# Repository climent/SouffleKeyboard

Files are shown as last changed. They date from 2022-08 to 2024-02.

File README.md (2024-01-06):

# Soufflé Keyboard

The Soufflé Keyboard is 6×4+1+4+1 keys column-staggered split keyboard with encoder support, based on the [Sofle](https://github.com/josefadamcik/SofleKeyboard) and re-inspired by the [Lily58](https://github.com/kata0510/Lily58) keyboards. It also takes a bit of layout ideas from the Kyria and the Ferris Sweep.

Soufflé was created by [Jesus Climent](https://https://github.com/climent/).

Key features:

*   Originally based on the Sofle V1 release layout,
    *   the two pinky columns have been lowered in the Soufflé: ~5mm for the V2, ~10mm for the V3 Sweep
    *   the thumb cluster has been repositioned to allow for equal reach of the keys
    *   a palm key has been added at the bottom of the outer pinkie column
*   Choice between rotary encoder or key switch for the inner keys.
*   Redone track layout with simplified, curved tracks.
*   V3 adds support for nice!nano with solder points for a battery and a power switch. 
*   Removed i2c communication betweek halves.

The VR release is a result of me experimenting with the RGB layout. However, I could not adapt to the displaced thumb cluster, so I returned to the V1 layout when I designed the V2.

## Images of keyboard

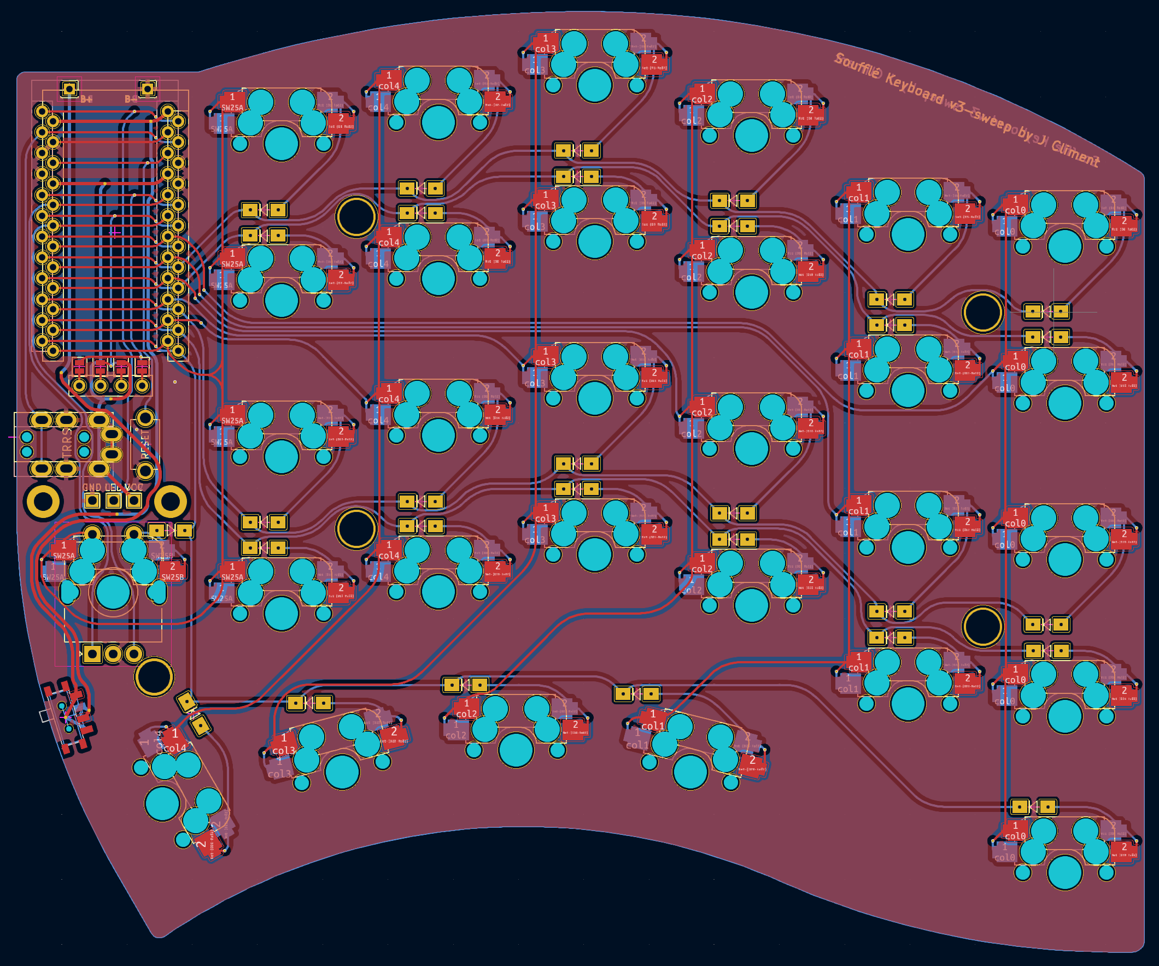
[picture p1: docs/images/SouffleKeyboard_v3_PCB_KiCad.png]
SouffleKeyboard PCB

SouffleKeyboard V3

## Build notes

Build guide will be added soon. Meanwhile, the [Sofle Build Guide](https://josefadamcik.github.io/SofleKeyboard/build_guide.html) should be a good starting point.

## BOM

| Item | Quantity | Notes |
|---|---|---|
| Soufflé PCB | 2 | |
| Soufflé Plates | 2+2 | Gerber files are provided to be ordered made of FR4. Can be 3D printed, extruding the upper plate at 1.5mm, the lower at a minimum of 1.5mm. |
| Pro Micro pin MCU, or equivalent. | 2 | RP2040 recomended. Alternatives: Pro Micro (or clone), Elite-C, Elite-Pi, Frood, Liatris, nice!nano (for BT wireless) |
| 1N4148W Diodes | 60 | |
| Kailh MX hotswap switch sockets | 60 | |
| MX switches | 60 | |
| 1u keycaps | 60 | |
| M2, 7 mm brass (or other material) spacers | 10 | These are the optimal spacers. Longer ones work, too, but with 7mm the gap is minimal. |
| M2x0.4mm, 5mm length flat head screws | 20 | |
| M2x0.4mm, 7mm length flat head screws | 4 | If using OLED screen plexiglass protectors. |
| PJ-320A TRRS 3.5mm Audio Jack Connector Through Holes | 2 | Not necessary if you are using wireless, via nice!nano. |
| Surface Momentary Tact Switch, 3mm x 4mm x 4.3mm | 2 | |
| 2.54mm Round Hole Male Tin Gold Female Pin Headers, 40p | 2 (opt)  | HIGHLY RECOMMENDED. However, If you want to solder the MCU directly to the board, these are not necessary. |
| Mill Max socket pins | 48 (opt) | Add 8 extra for the OLED screen, if used. Alternatively, socketing can also be done with diode legs. |
| 1.25u keycaps | 2 (opt)  | Alternative to 2x 1u keycaps. |
| SSD1306 128x64 OLED | 2 (opt)  | |
| EC11 Encoder | 2 (opt)  | Optional, as the board allows for either 2x encoders or switches. |
| Encoder knob, 16mm | 2 (opt)  | If encoders are used. |
| M2, 10 mm brass (or other material) spacers | 4 (opt)  | If using OLED screen plexiglass protectors. |
| MSK12C02 power switches | 2 | If using nice!nano MCUs and batteries, for BT wireless. |
| Battery, 10mAH | 2 | If using nice!nano MCUs and batteries, for BT wireless. |
| TRRS audio cable, for connecting both sides | 1 (opt)  | Not necessary if you are using BT wireless, via nice!nano. |

## Firmware 

Soufflé uses [QMK firmware](https://qmk.fm/) and it is fully compatible with the Sofle firmware.

## Default layout 

Soufflé uses a similar layout than the Sofle, with a full 6x5 matrix, and the encoders connected to the same pins. The main difference is the position of the outermost thumb key, which has been moved to the bottom of the pinky column, to be used with the palm.

## Older versions

In this repository you will find several  releases of the Soufflé Keyboard:

*   V1: Based on the Sofle v1 and the Lily58. Key features:
    *   Added the palm key at the bottom of the pinky column.
    *   Some re-routing done and some label fixes, but modtly unchanged from the Sofle v1.
*   VR: Based on the Sofle RGB. Key features:
    *   Same palm key configuration as the V1.
    *   The layout footprint is based on the RGB, and thus the thumb cluster is slightly displaced to the center (compared to the V1).
    *   The encoder footprint shares a switch footprint, allowing for the user to choose what to put there.
    *   Pins for the encoder/switch have been exposed, as the top case plate can accommodate a roller encoder.
*   V2: Based on the Soufflé V1. Key features:
    *   Same palm key configuration as the V1.
    *   Pinkie columns have been lowered.
    *   Thumb cluster repositioned, to make the keys slightly more accessible.
    *   The encoder footprint shares a switch footprint, allowing to choose what to put there.
    *   Removed I2C connectivity option.
    *   Curved contour of the keyboard.
*   V3: Based on the Soufflé V2, and the Ferris Sweep layout. Key features:
    *   Wireless compatible with Nice!Nano MCUs.
    *   Same palm key configuration as the previous releases.
    *   Pinkie columns have been lowered even further, similar to the Ferris Sweep keyboard.
    *   Middle finger column has been raised, similar to the Ferris Sweep keyboard.
    *   Thumb cluster repositioned, to make the keys slightly more accessible, as the V2.
    *   The encoder footprint shares a switch footprint, allowing to choose what to put there, as the V2.
    *   The reset button has been repositioned, and is accessible through a hole in the lower plate.
    *   Added battery connection points, and a power switch, for use with nice!nano.
    *   Removed I2C connectivity option.
    *   Curved contour of the keyboard.
*   V3.1: Small upgrade to the V3
    *   Added a compatibility pin for Nice!View screens.

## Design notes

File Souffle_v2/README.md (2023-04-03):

# Soufflé Keyboard v2

Soufflé v2 is 6×4+1+4+1 keys column-staggered split keyboard with encoder, OLED, and palm key support. It is an evolution of the Soufflé V1 and VR keyboard, with a slightly more aggressive arrangement of the pinkie columns.

Soufflé V2 was created by [Jesus Climent](https://https://github.com/climent/).

Key changes compared to the Soufflé V1:

*   Pinkie columns have been lowered ~5mm, to make them more accessible.
*   Thumb cluster repositioned, to make the keys slightly more accessible.
*   It is now possible to use switches in the position of the 2x rotary encoders.
*   Curved contour of the plates.

## Firmware 

Soufflé v2 uses [QMK firmware](https://qmk.fm/) and it is fully compatible with the Sofle firmware.

## Images of keyboard

SouffleKeyboard V2 top view
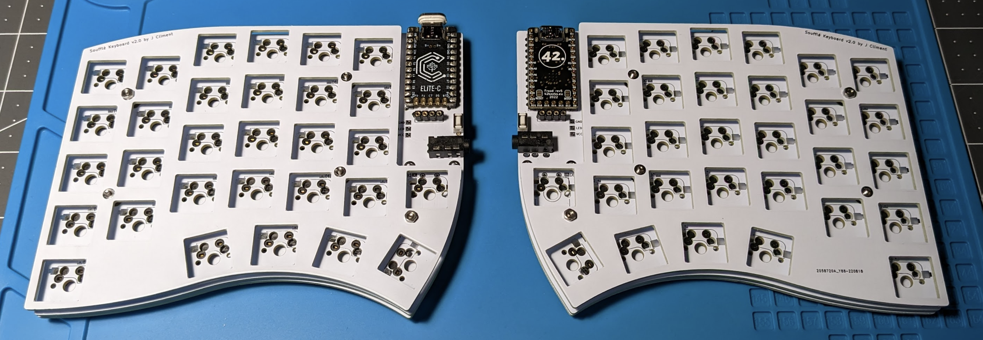
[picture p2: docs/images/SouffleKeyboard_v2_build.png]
SouffleKeyboard V2 build picture


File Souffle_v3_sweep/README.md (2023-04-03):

# Soufflé Keyboard v3 Sweep

Soufflé v3 is 6×4+1+4+1 keys column-staggered split keyboard with encoder, OLED, palm key and nice!nano support. It is an evolution of the Soufflé V2 keyboard, with a more aggressive arrangement of the pinkie columns.

Soufflé V3 Sweep was created by [Jesus Climent](https://https://github.com/climent/).

Key changes compared to the Soufflé V2:

*   Pinkie columns have been lowered ~5mm (~10mm compared to V1), to make them more accessible.
*   Middle finger column has been raised ~3mm.
*   Reset button has been moved to an internal position, and the lower plate has a hole, making it accessible from the bottom of the keyboard.
## Firmware 

Soufflé v3 Sweep uses [QMK firmware](https://qmk.fm/) and it is fully compatible with the Sofle firmware.

## Images of keyboard

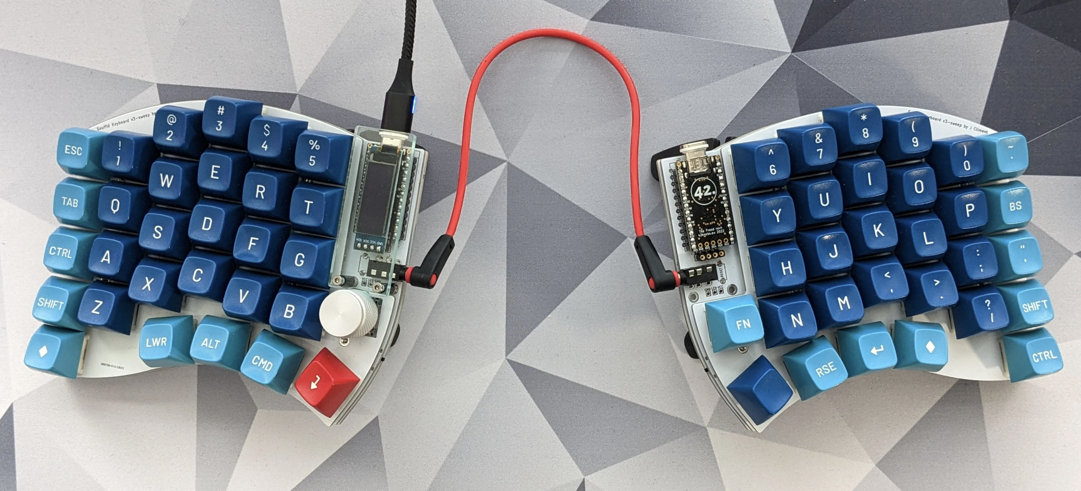
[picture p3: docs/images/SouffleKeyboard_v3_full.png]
SouffleKeyboard PCB

SouffleKeyboard PCB
SouffleKeyboard PCB

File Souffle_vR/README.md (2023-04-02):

# Soufflé Keyboard

Soufflé vR is 6×4+1+4+1 keys column-staggered split keyboard with encoder support, based on the [Sofle](https://github.com/josefadamcik/SofleKeyboard) RGB version, and re-inspired by the [Lily58](https://github.com/kata0510/Lily58) keyboard.

Soufflé was created by [Jesus Climent](https://https://github.com/climent/).

Key features:

*   Palm key at the bottom of the outer pinky column.
*   2x rotary encoders.
*   Original RGB features were removed.
*   Exposed pins for roller encoder on the upper case plate. 
*   More (to be listed).

## Firmware 

Soufflé uses [QMK firmware](https://qmk.fm/) and it is fully compatible with the Sofle firmware.

## Default layout 

Soufflé uses a similar layout than the Sofle, with a full 6x5 matrix, and the encoders connected to the same pins. The main difference is the position of the outermost thumb key, which has been moved to the bottom of the pinky column, to be used with the palm.

## Images of keyboard

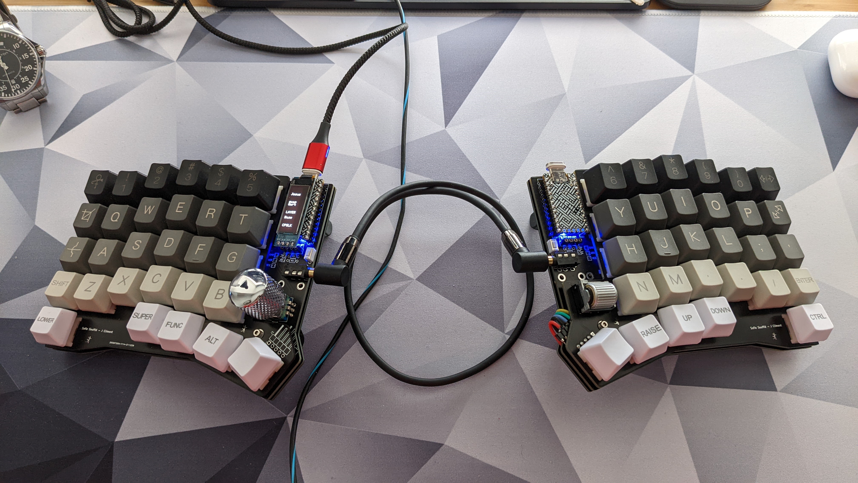
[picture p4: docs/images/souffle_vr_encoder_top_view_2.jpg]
SouffleKeyboard PCB


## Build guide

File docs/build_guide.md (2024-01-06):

---
layout: default
title: Soufflé Keyboard - build guide (v3)
---

This guide is for the V3 (Sweep release) of the Soufflé keyboard, but it can serve as a base guide for any other Soufflé revision.

If you don't have all the necessary parts, please read about [how to source the parts][sourcing].

## Bill of materials

The following is needed to build the keyboard. You can find [links for the most of the components in the sourcing parts section][sourcing].

- **2 PCBs** (see [sourcing][sourcing])
- **2 top plates**, **2 bottom plates** for a sandvich-case build. (see [sourcing][sourcing])
- **58-60 keyboard switch sockets by Kailh**. The PCB supports only MX switches. A Choc version of the Soufflé keyboard will be available some time in the future. They are available on Aliexpress, Splitkb.com and others. 
- **58-60 keyboard MX switches** of your preference.
- **58-60 keycaps**. You can use either all in `1u` size but it looks nicer with two `1.5u` for the thumb keys.
- **58-60 diodes  1N4148W**. They are surface mount diodes in SOD123 package.
- **2 TRRS connectors**. The same type which is used for Corne, Lily58 etc.
- **2 tactile buttons** through-hole, 2 pins. Technically optional: you can use metal tweezers whenever you need to reset the microcontroller.
- **1 TRRS cable**. TRS should work.
- **10 7mm M2 spacers**. They will hold the bottom and the top together. 
- **4 10mm M2 spacers**. Needed to hold transparent OLED cover but even though there are mounting holes in the PCB.
- **20 (+8) 5mm M2 screws**. 20 are going to hold the boards together (via spacers).
- **10 adhesive rubber feet**. They are really important, trust me.
- **0-2 ssd1306 128x32 OLED display module**. Very common everywhere. 
- **2 OLED covers** Optional. OLED cover should be cut from transparent acrylic. Source file for [version 1 is avalalble in the Sofle repostiory](https://github.com/josefadamcik/SofleKeyboard/tree/master/Sofle_v1/Case).
- **0-2 Rotary encoders EC11**, optional. The Soufflé is ready to accept either switches or encoders in one position.
- **A matching knob** for each encoder. 
- **2 Pro Micro** board or clone. With 2x12 pins. Just make sure you **don't** buy something like Arduino Micro (a different pinout) or Arduino Mini (different microcontroller). You could also use Elite-C which in basically a Pro Micro with USB-C. New microcontrollers based on the Raspberry Pico (rp2040) are available, and have more memory.
- **4x12 pin header (and optionally socket)** for Pro Micros. There are several ways how to mount Pro Micros to the board. Either the male PIN headers you most likely got with the board from the supplier could be used to solder it directly to the board. Build guides for Helix, Corne and Lily58 suggest [those spring pin headers][springpinheader] which are very compact and give you non-permanent connection (you can remove or replace Pro Micros). Another possible approach [is described at splitkb.com][promicrosocketing].
- **2x4 pin header (and optionally socket)** for OLEDs. I have used the most common 1x4 female pin sockets which are quite tall but they also fit the height of ProMicro with the sockets I have used. Unfortunately, the pin headers on my OLED modules (again those very common square male headers you would get with the modules) are loose in the sockets. It works but it's fiddly. I'll have to find a better solution.
- **USB Cable** to connect the keyboard to a computer. As a favourite, I use magnetic cables, to avoid putting too much stress into the USB connector.

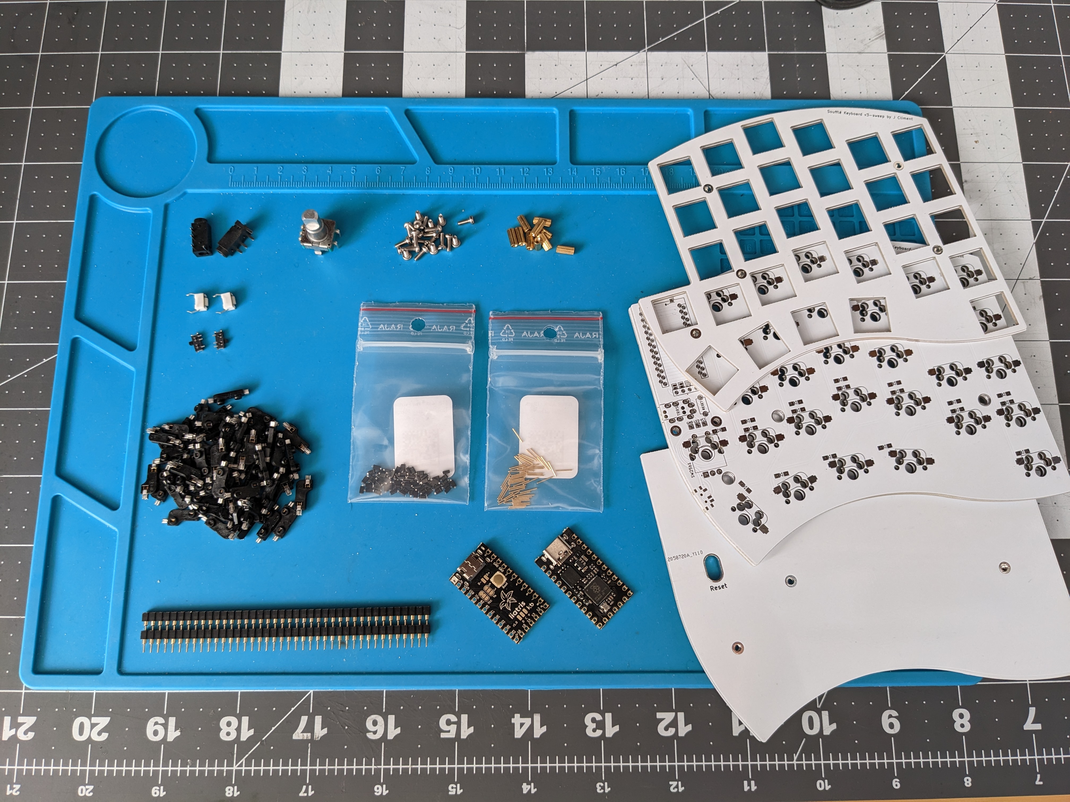
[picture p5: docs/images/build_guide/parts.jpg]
SouffléKeyboard parts


That's it. There are no RGB LEDs on the board. But if you really need underglow it is be possible to connect an RGB LED strip since there are 3 pads (VCC, GND and data) on the board. You would need to add support to the firmware on your own.

## Tools and materials

- soldering iron
- solder wire
- good tweezers, preferably non-magnetic
- masking tape
- isopropyl-alcohol for cleaning 
- screwdriver

## Warnings and disclaimers

- Think twice, solder once. Desoldering is frustrating and it's easy to mess up things.
- Don't connect or disconnect the TRRS cable when the keyboard is powered. It may short out. Always disconnect the USB cable first.
- If you are not using magnetic cables, be gentle with the USB on your microcontroller. They are easy to break.

## Steps

### Prepare

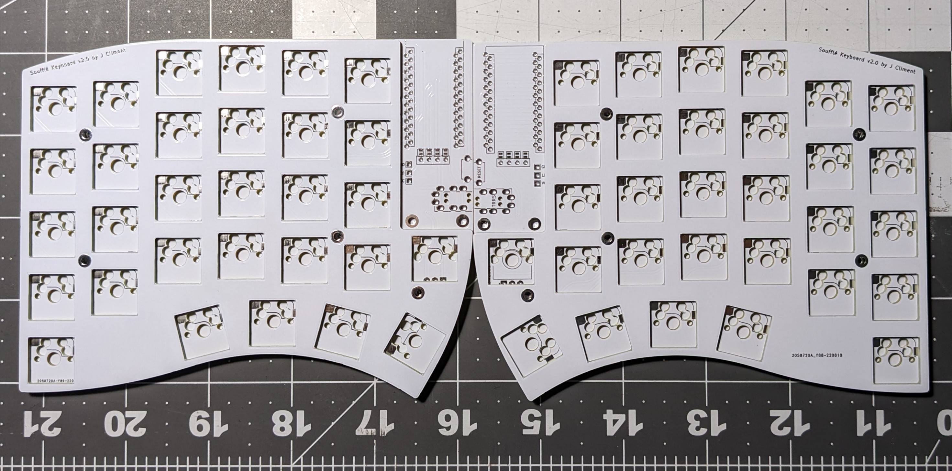
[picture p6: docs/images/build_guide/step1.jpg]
Step 1


Make sure you have all the right parts for the keyboard, specially the PCB and the top and bottom plates match. Some people mark the top/bottom of the keyboard with masking tape. I owrk with both PCBs at the same time, thus making sure I am soldering the right side on both PCBs.

### Components on the backside 

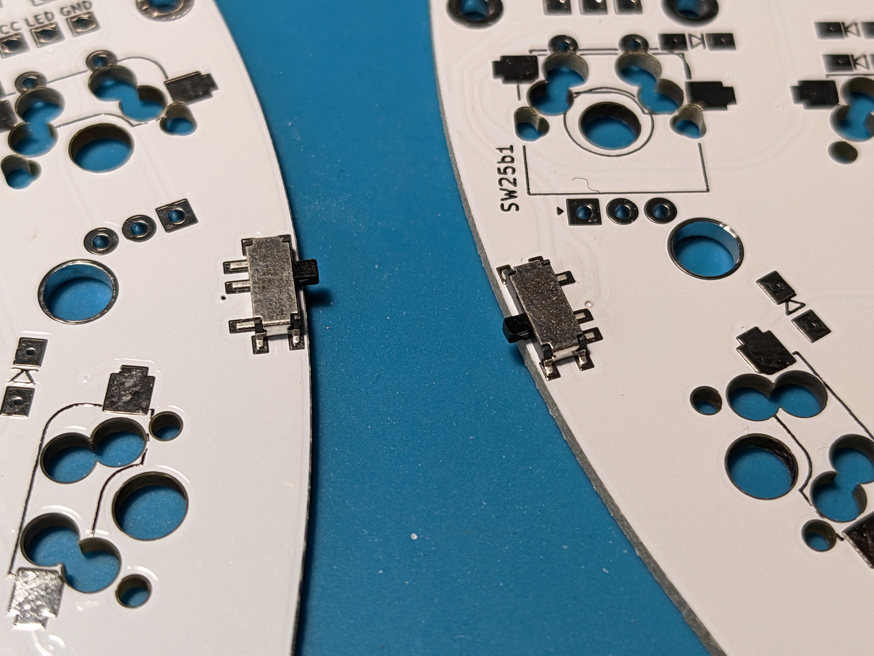
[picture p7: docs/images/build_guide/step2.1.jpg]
Step 2.1

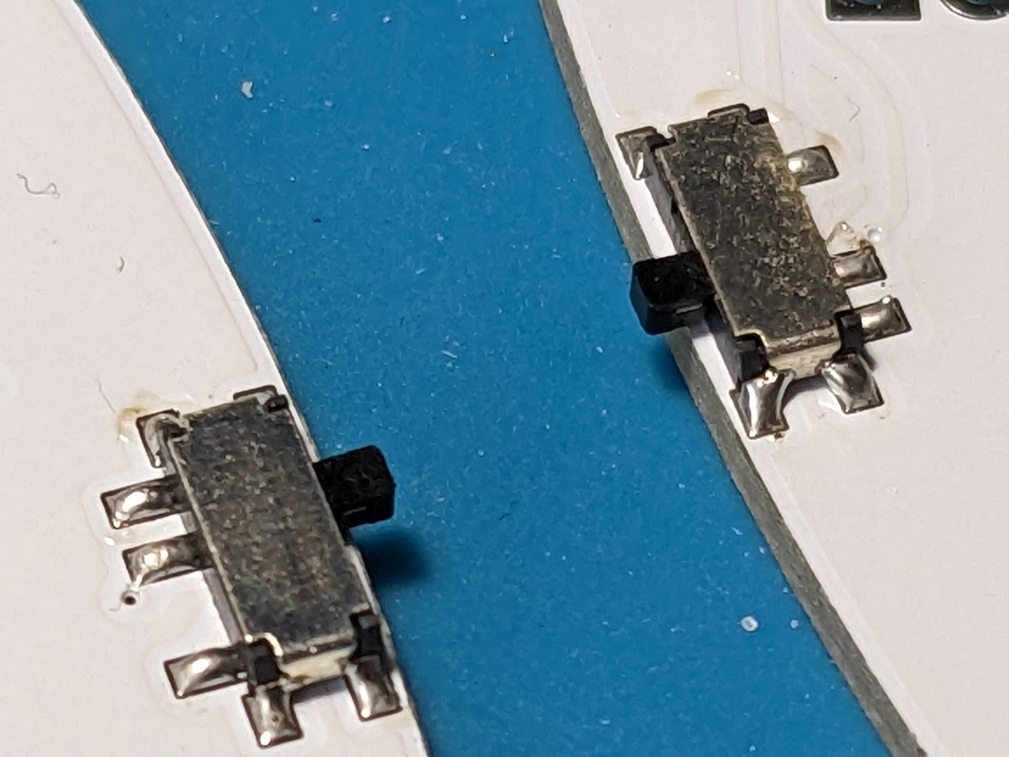
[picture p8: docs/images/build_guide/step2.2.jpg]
Step 2.2


Only if you are using, or plan to use, nice!nano microcontrollers.

Start with the power switches. Place them on the bottom side of the boards, and solder the pins to the PCB.

Next step is the diodes. They go on the backside of the PCB. Make sure you have orientation right. The end with the thin line is Cathode (-) and it should go in the direction of the "arrow" symbol on the PCB.

Step 3.1
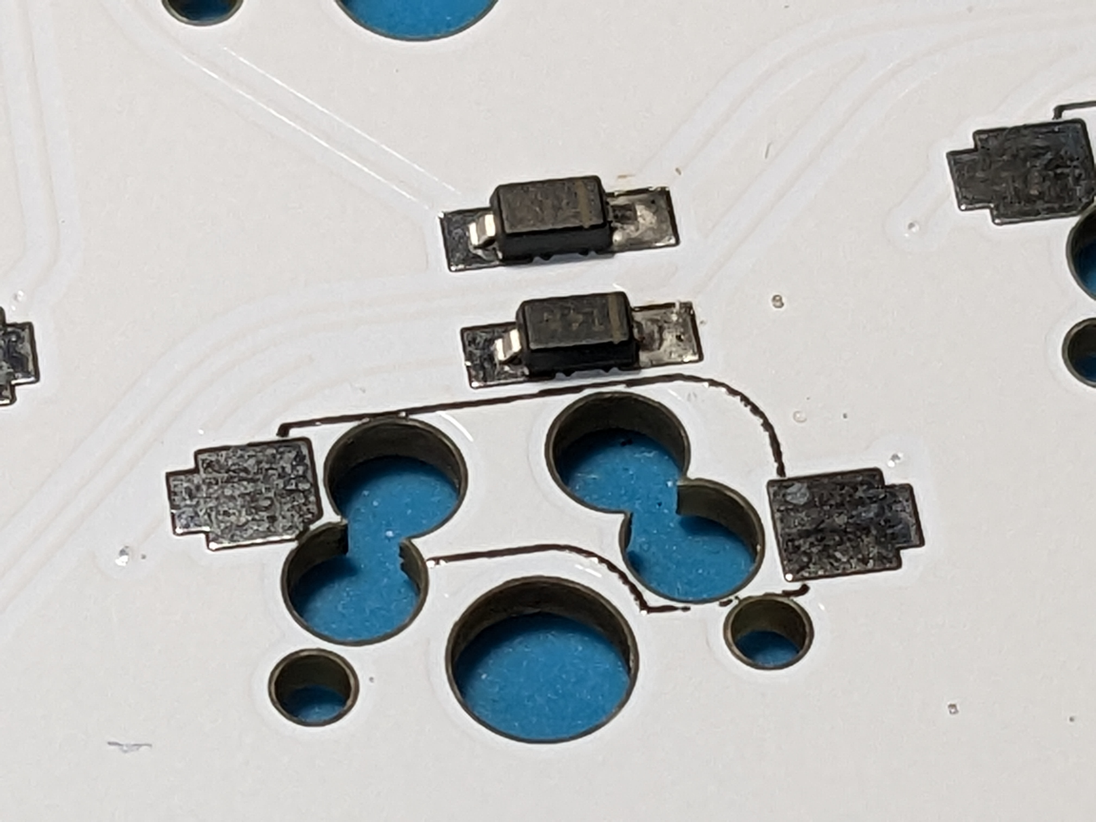
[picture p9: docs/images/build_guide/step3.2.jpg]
Step 3.2


Add a bit of solder wire to one of the two diode pads on every diode footprint of both boards. This way you can then solder one of the diode's side without needing 3 hands: one for the solder iron, one for the diode, and one for the solder wire. Use the antimagnetic tweezers to hold the diode while re-heating the solder paste on the pad, and making sure you place the diode with the correct orientation.

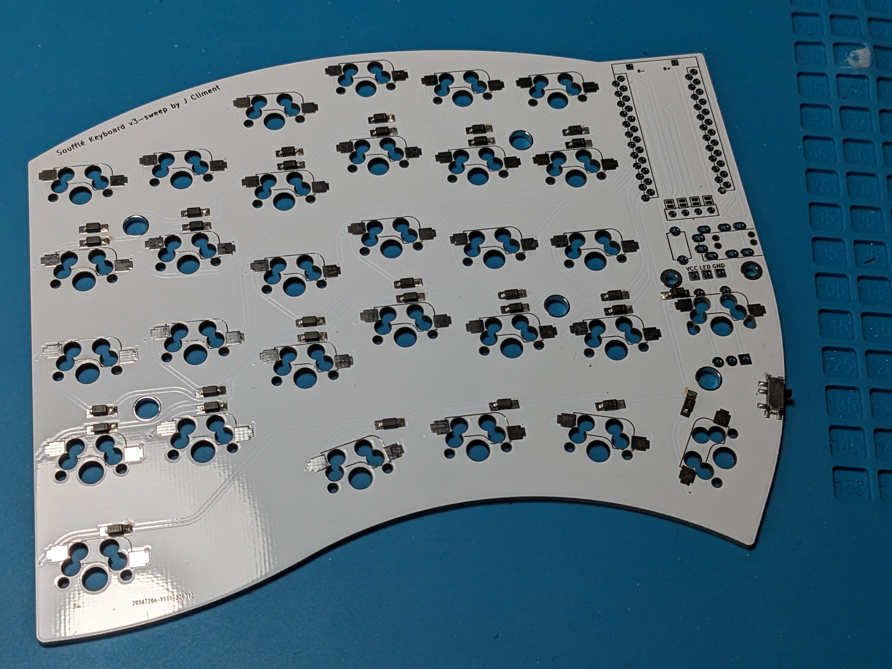
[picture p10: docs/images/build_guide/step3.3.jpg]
Step 3.3

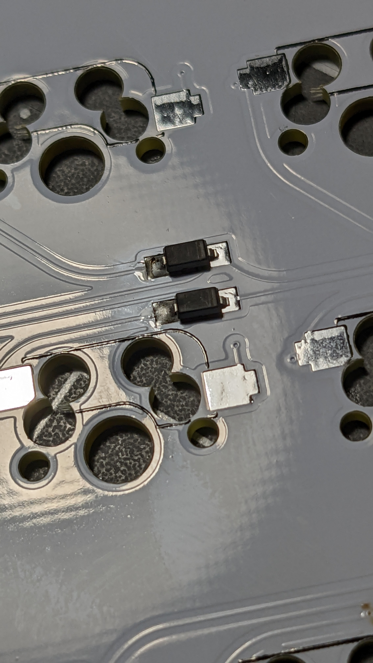
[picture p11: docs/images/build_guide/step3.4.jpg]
Step 3.5

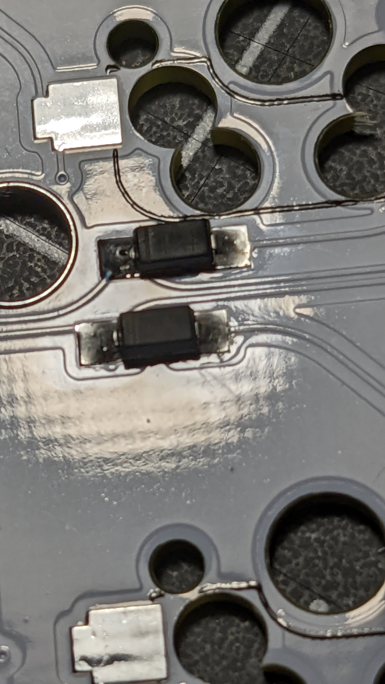
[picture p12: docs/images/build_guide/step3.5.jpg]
Step 3.4


Finally, solder the other pad and complete the diodes on both sides.

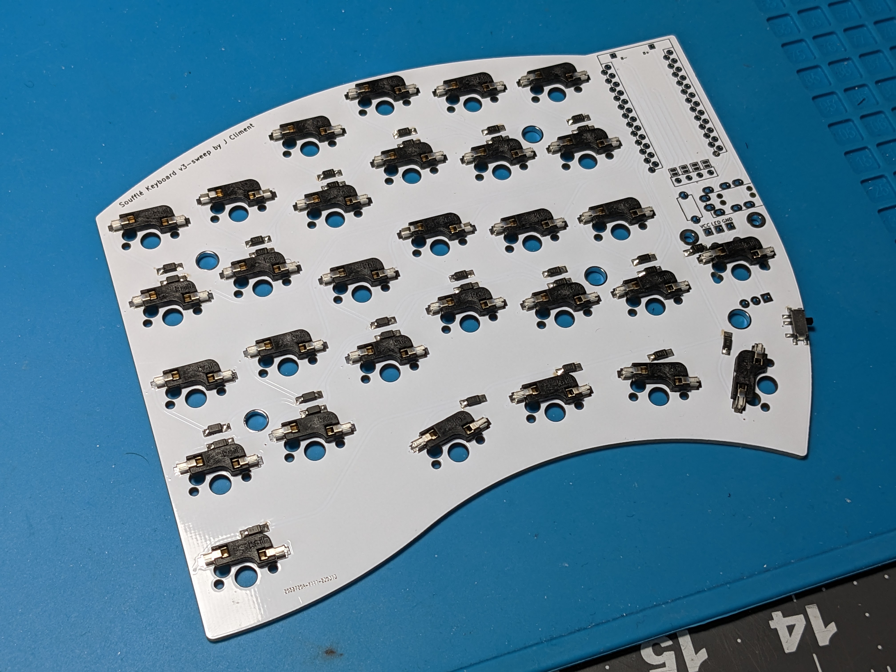
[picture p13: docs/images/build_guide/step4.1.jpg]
Step 4.1


The sockets for the switches belong again on the back side, the same side as diodes. Make sure they are flush with PCB. Watch the markings on the silkscreen which show the correct orientation.

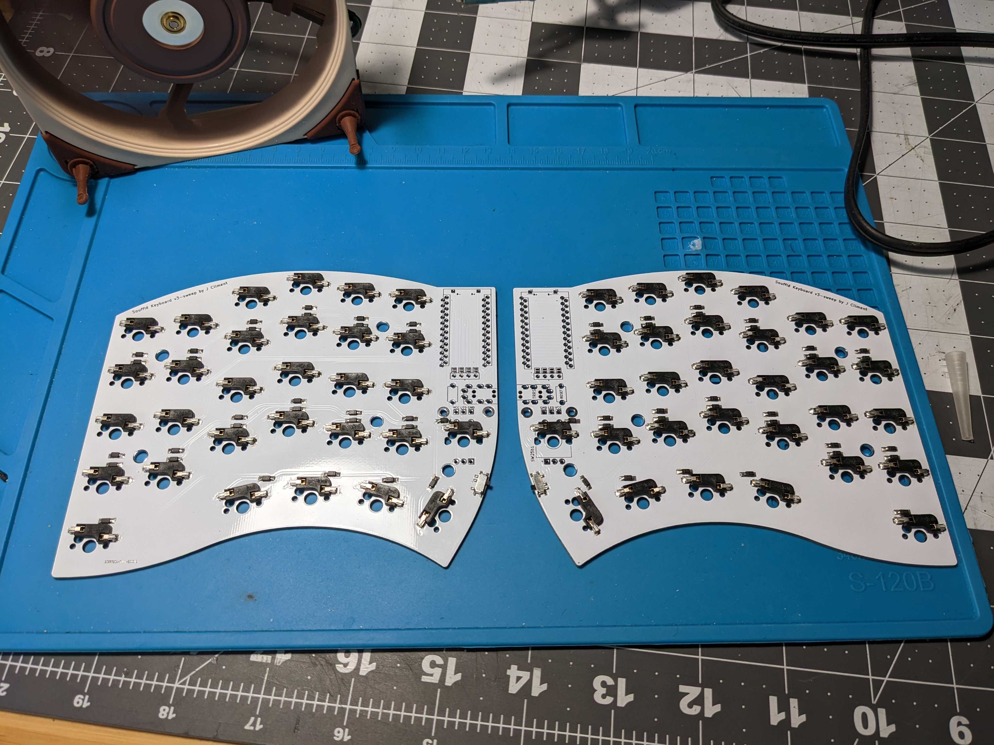
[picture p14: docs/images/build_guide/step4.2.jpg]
Step 4.2


Soldering one pad of the socket for all the sockets at once, approaching the sockets from the same side, makes it easier to work with them. Once one side is soldered, turn around the PCB and solder the other pad.

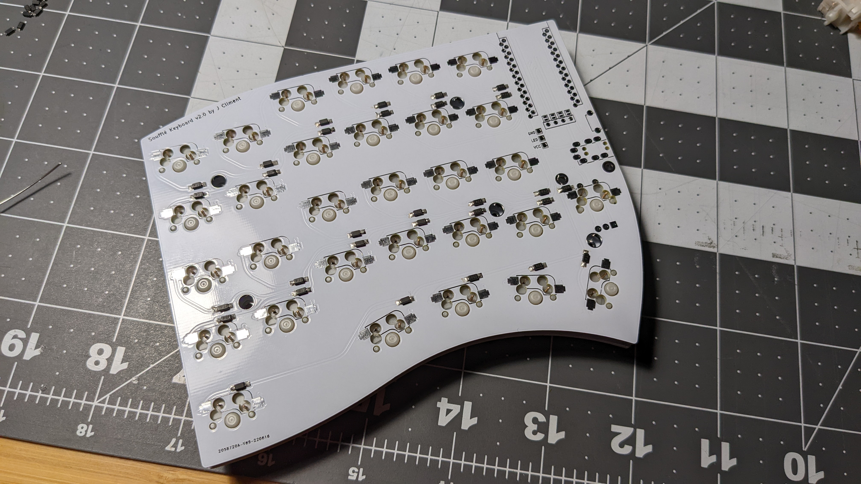
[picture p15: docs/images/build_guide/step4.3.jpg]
Step 4.3


A way to keep the MX sockets in place while soldering them is by using the switches. Put the switches in place (upper side of the PCB), and add the sockets to the bottom side. Now soldering sould be easier.

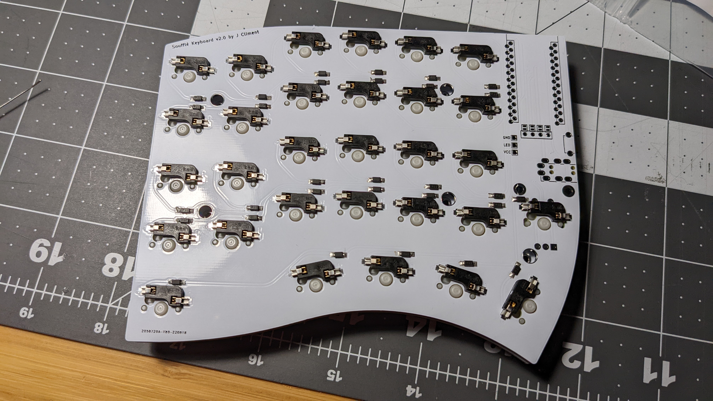
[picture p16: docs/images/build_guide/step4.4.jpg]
Step 4.4

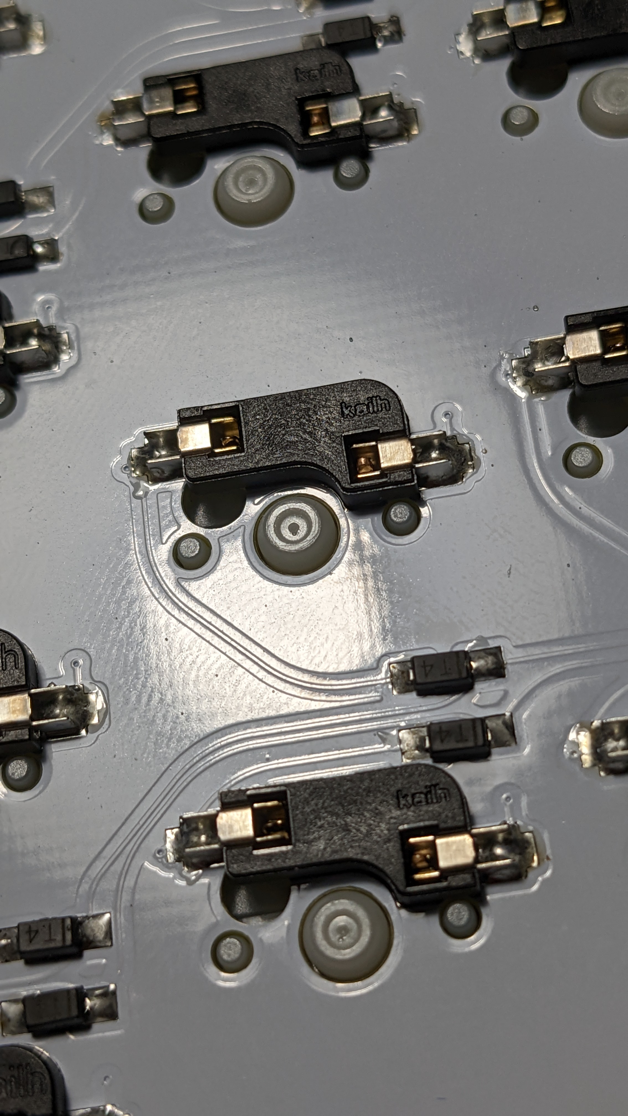
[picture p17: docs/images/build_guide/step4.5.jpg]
Step 4.5


### Components on the front side

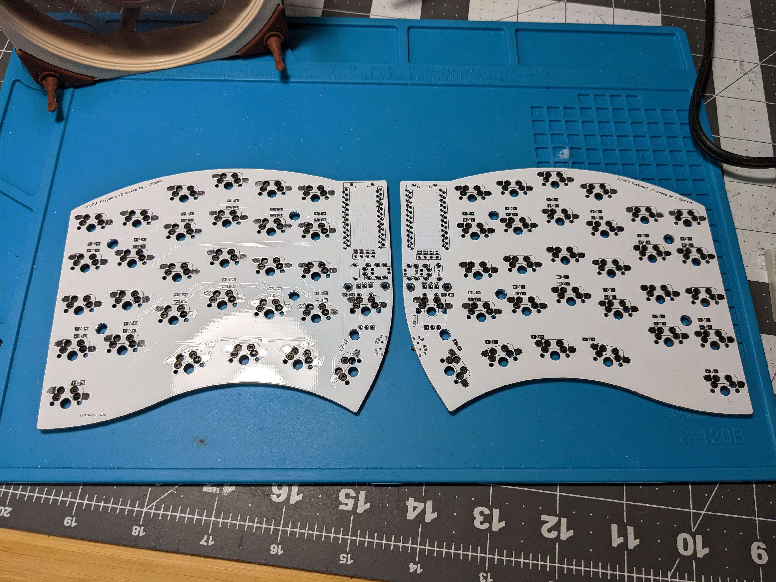
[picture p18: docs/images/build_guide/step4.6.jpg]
Turn the PCBs around


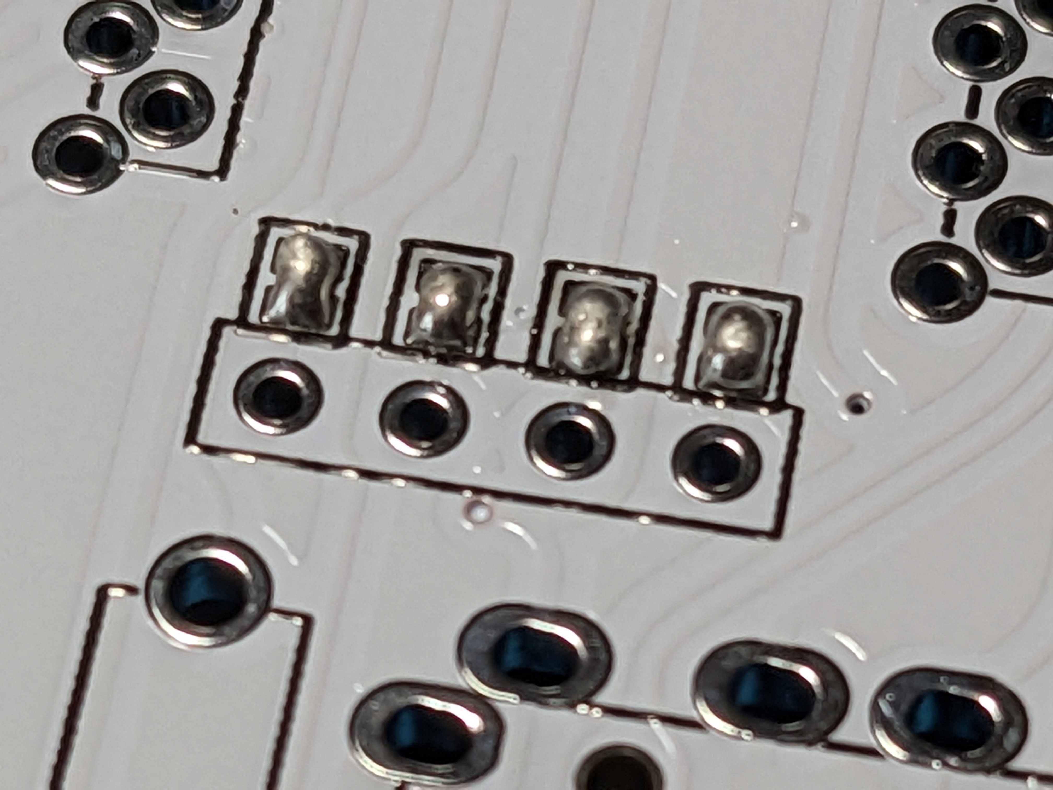
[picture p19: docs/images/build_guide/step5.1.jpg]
Step 5.1

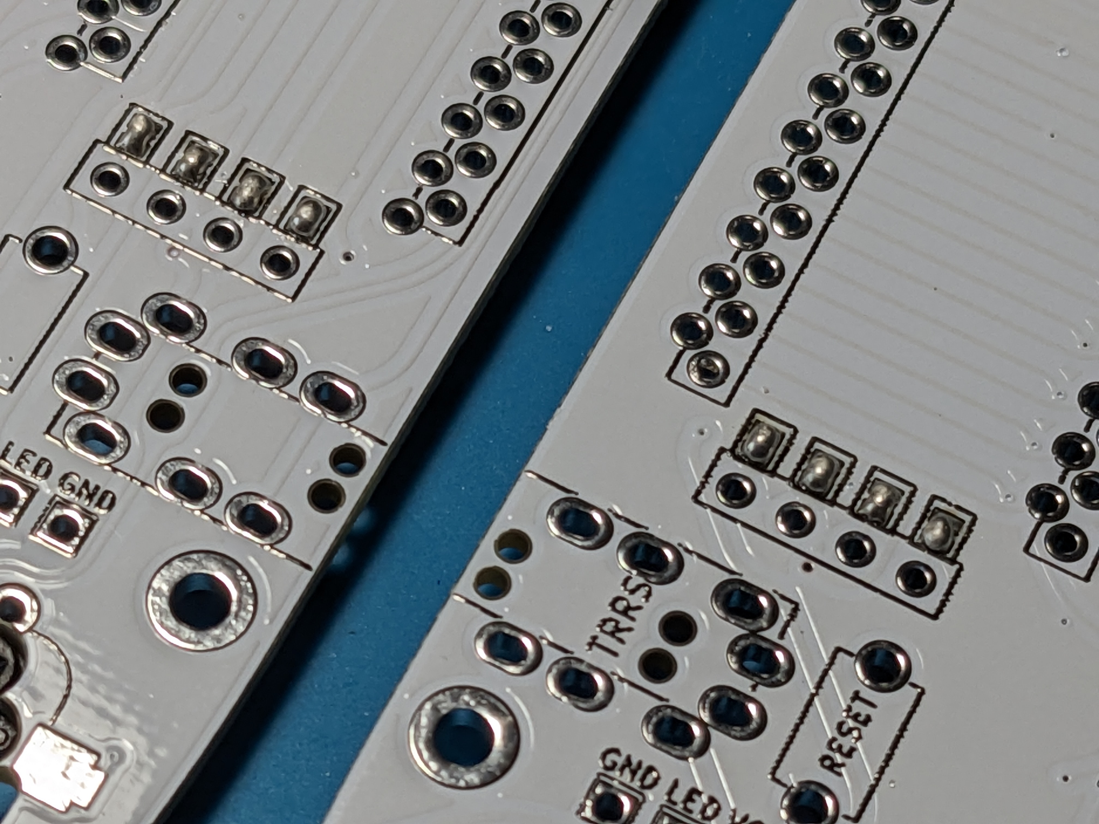
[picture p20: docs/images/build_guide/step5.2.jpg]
Step 5.2


Solder the jumper pads for the OLED on the top side of the PCB.

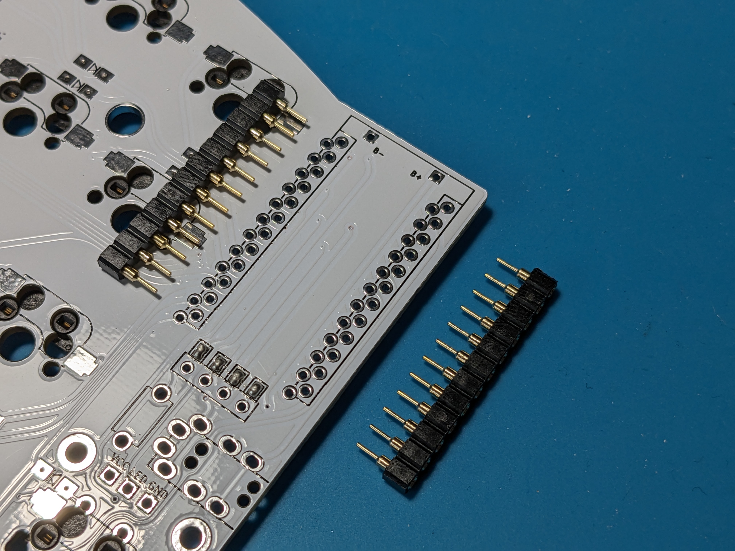
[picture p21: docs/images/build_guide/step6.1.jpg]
Step 6.1

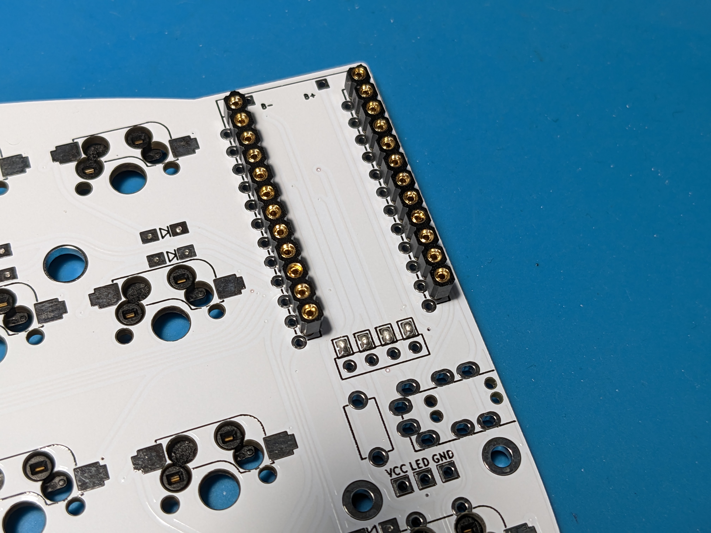
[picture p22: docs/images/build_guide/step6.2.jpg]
Step 6.2


If you are using sockets for the microcontrollers, place them on each side covering the marked rectangle. This way the microcontroller will go face down.

Although sockets are optional, I encourage you to use them. If you solder the microcontrollers directly to the PCB and there are problems with them, you will have a hard time desoldering them.

Note: if for whatever reason you want to place the microcontrollers with the chip facing up (some boards come with LEDs, or boot/reset switches on the upper side, or you are planning to place a small battery under the microcontroller, and want to avoid the chip and the components using that space), you can place the sockets on the non-marked pin holes.

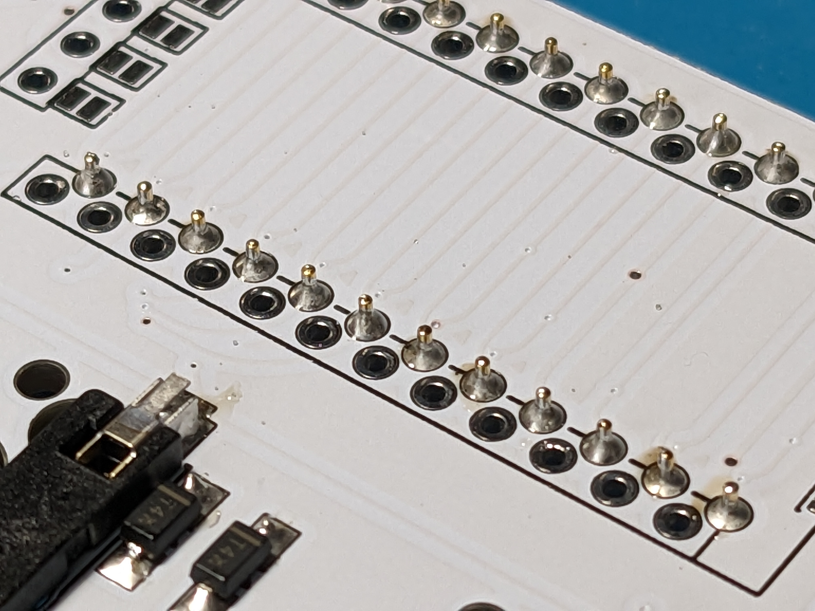
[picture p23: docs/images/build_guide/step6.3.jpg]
Step 6.3


Some people use masking tape to keep the sockets in place. I instead follow this process: I solder a single pin on one end of the socket. Once that pin is soldered, I reheat the solder while settling the socket with my thumb. This way I make sure the socket is push all the way through and at the right angle. Then I solder the pin on the other side. Then I reheat the pin with the soldering iron while I push the socket to make sure is completely pushed to the right location. I then proceed to solder all the other pins.

Solder the socket pins from the bottom side, making sure the solder does not overflow to the other pin holes. If the solder overflows, you will need to remove it, as that will short the connections to the switches. 

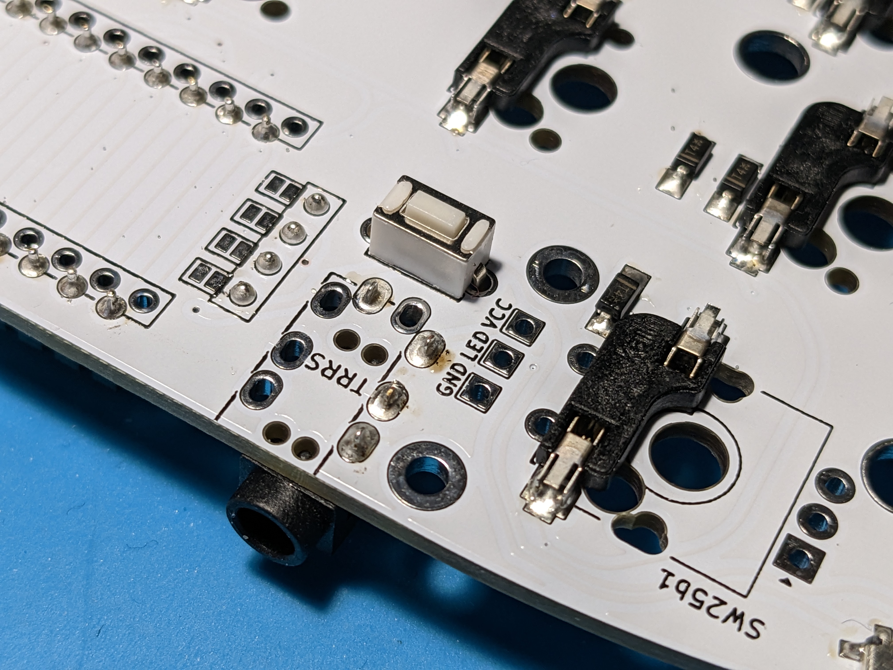
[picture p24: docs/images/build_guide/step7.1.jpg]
Step 7.1


TRRS sockets go on the top. Use a piece of masking tape to fix them and apply solder from the bottom side.

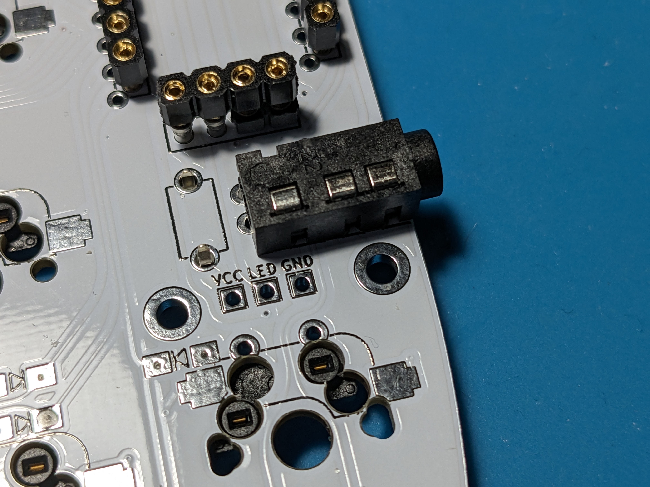
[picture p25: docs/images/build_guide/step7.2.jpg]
Step 7.2


Reset switches go either on the bottom side (there is a hole in the bottom plate to access the switches), or you can place them on the top, if you don't plan to use plexiglass protectors. In any case, solder from the opposite side.

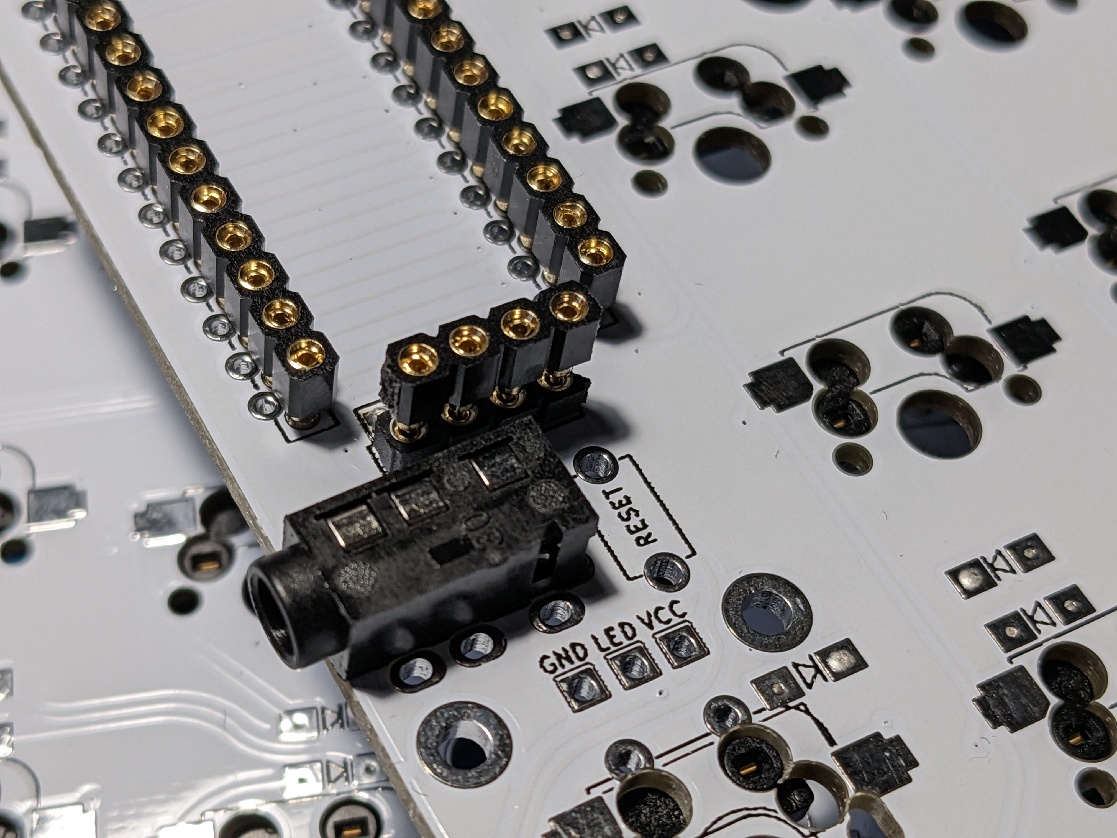
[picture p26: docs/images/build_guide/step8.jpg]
Step 8


Finally place the 4-pin socket for the display, keep it in place with masking tape (or repeat the procedure I follow, soldering a single pin and correcting the placement while heating the pin, etc), and solder it. In this picture you can see I have used medium profile sockets for the microcontroller so that a battery fits under it, and i have soldered a low profile socket and added a medium profile socket on top. This way the OLED screen can rest on top of the microcontroller, after you make sure you add some kapton tape (or other form of isolation) to avoid shorting the micro. There are other options out there to keep the OLED above the micro, like higher sockets.

### Pro Micro and display pins

There are several ways how to connect the microcontrollers to the boards. You can solder them directly to the PCB, using headers (you most likely received them with the micros). Once again, I encourage you NOT to do that. I have had instances in which the micro was faulty and it would have been a nightmare to desolder it and resolder a new one.

If you use sockets, I have used component "legs", similar to what you can find in this [Splitkb article](https://docs.splitkb.com/hc/en-us/articles/360011263059). However I prefer using Mil Max rounded pins, as they are stronger.

**Keep in mind the orientation of the microcontroller**. If you placed the sockets (on the upper side of the PCBs) over the rectangles, the microcontrollers are placed face down.

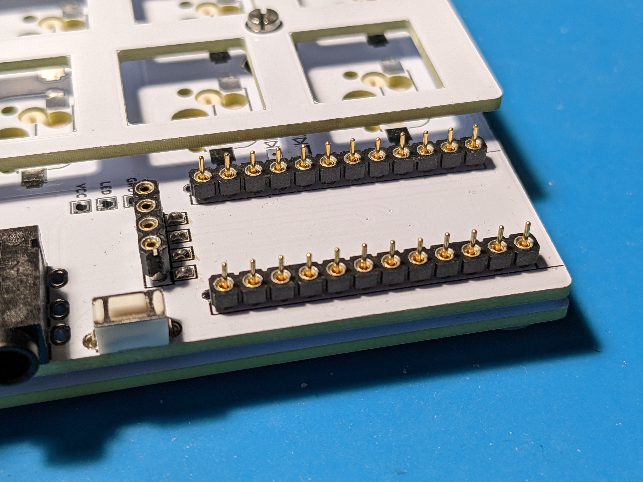
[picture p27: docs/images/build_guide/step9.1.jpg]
Step 9.1

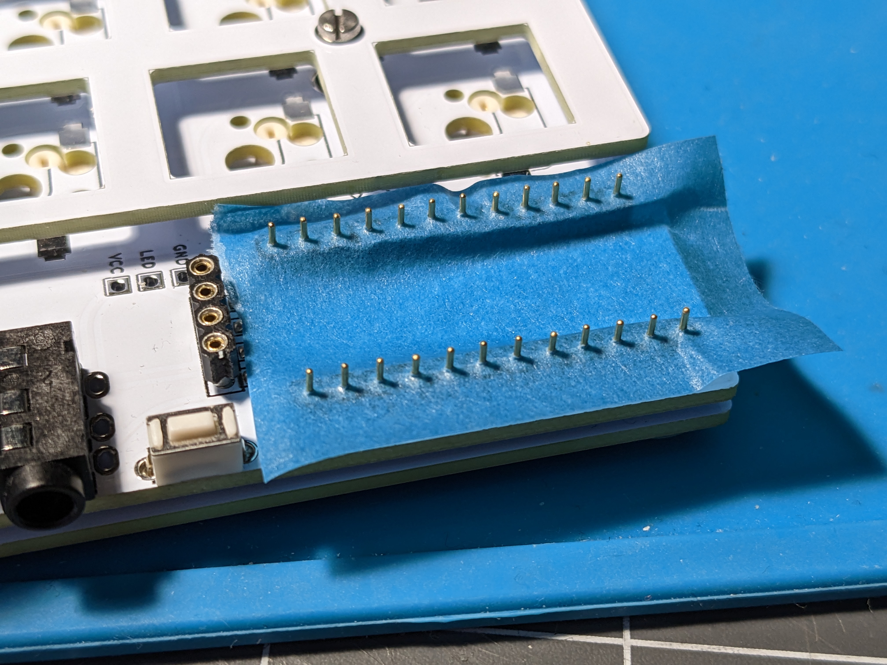
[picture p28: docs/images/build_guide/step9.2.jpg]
Step 9.2

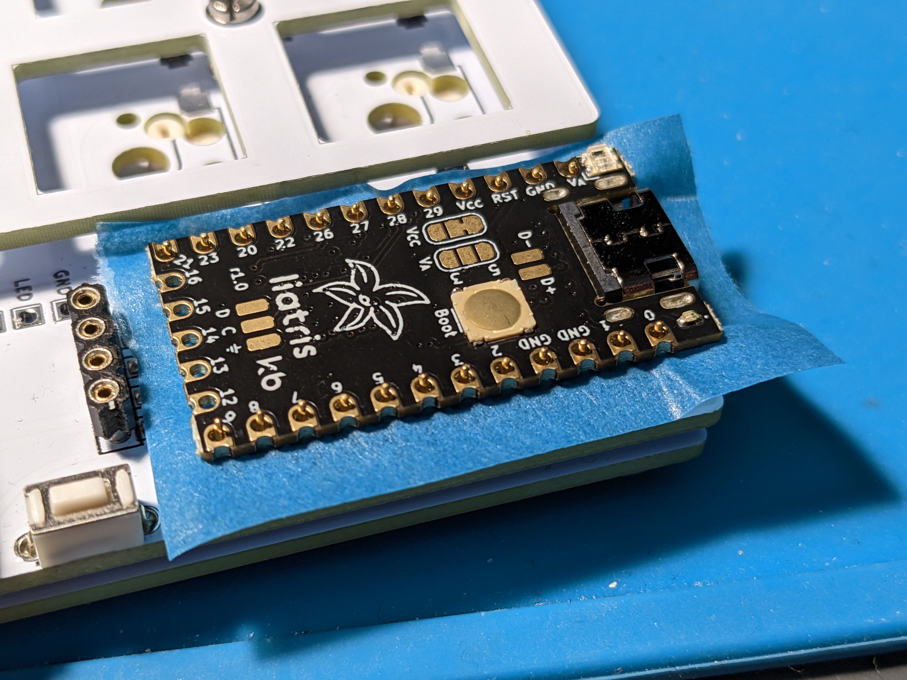
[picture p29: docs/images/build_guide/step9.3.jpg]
Step 9.3

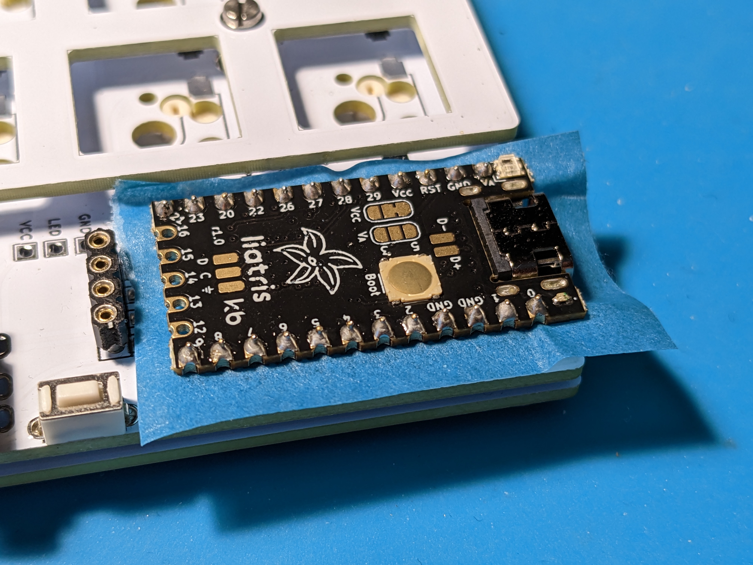
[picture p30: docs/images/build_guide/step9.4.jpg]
Step 9.4


I usually place the Mil Max pins on the sockets, place some masking tape (to avoid the solder reaching the socket, and thus making it impossible to remove the micro), place the micro on top, and solder the pins.

Follow the same process for the OLED displays, if you are using any.

### First test

Step 9.2

Now it is already possible to connect the microcontrollers and OLED displays to the boards, flash the firmware and check if all keys work using a piece of wire or tweezers, shorting all the pads on the switch sockets.

### Rotary encoders

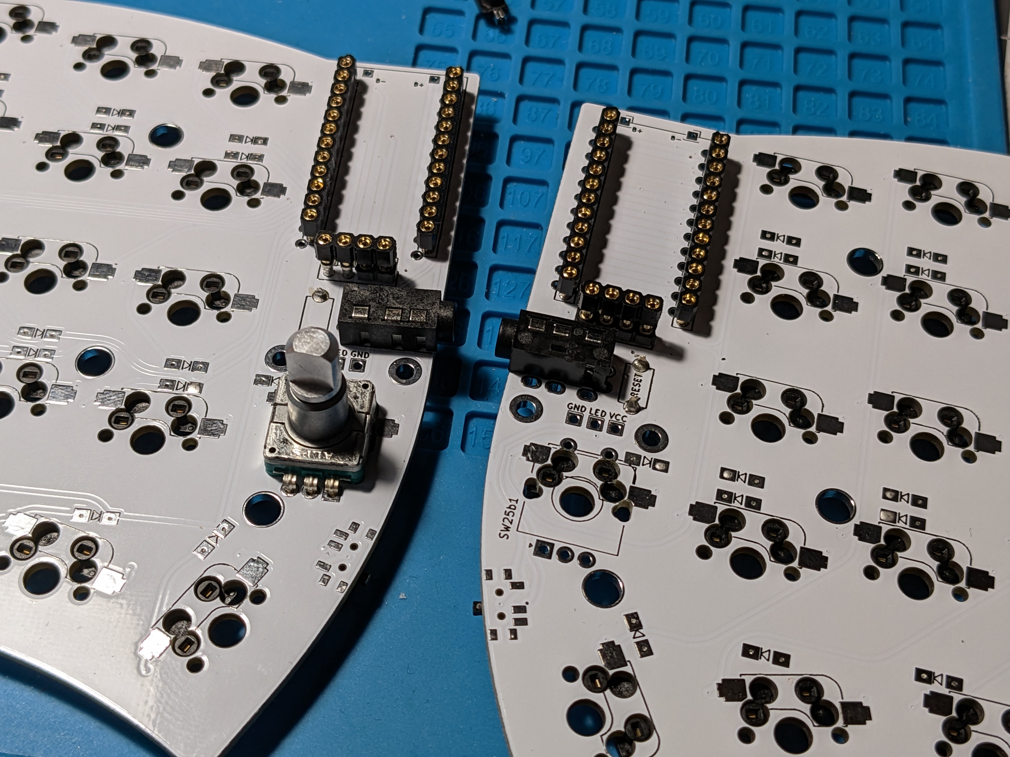
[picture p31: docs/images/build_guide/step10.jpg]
Step 10


Both halves assembled, a rotary encoder can be added on both, one or none. I have also cleaned flux residue from the back side using some isopropyl alcohol, cotton buds and paper towels.

### Keyboard switches and plates

Step 14

Snap first switches into corners.

Step 15

Mount the stand-offs to the top plate.

Step 16

Carefully snap the first switches to the sockets. Be careful so you don't bend their contacts. Add more.

Step 17

Until they are all in place.

Step 18

Double-check the bottom. You should see all the contacts in sockets.

Step 19

And mount the bottom plate.

Step 20

Completed half of the keyboard waiting for keycaps.

### Finishing touches

Step 21

Put at least 4 adhesive rubber feet in the corners so the keyboard is not sliding over your desk when you type.

## Warnings and disclaimers

- Don't connect or disconnect the TRRS cable when the keyboard is powered. It may short out. Always disconnect the USB cable first.
- If you are using microcontrollers with micro USB ports and not using magnetic cables, be gentle when you connect and disconnect your USB cable. They connectors are really easy to break.

## Firmware and programming

Soufflé keyboard uses [QMK Firmware][qmk_firmware], and uses the same connections than the [Sofle keyboard rev1](https://github.com/josefadamcik/SofleKeyboard/tree/master/Sofle_v1). Support for the board is part of the [main QMK repository](https://github.com/qmk/qmk_firmware/tree/master/keyboards/sofle/rev1). There's also a basic support in [QMK Configurator][qmk_configurator].

The best approach is to build the firmware yourself. You should be familiar with QMK and be able to make it work on your local environment. If not, please [follow the instructions in the documentation][qmkintro].

- Make sure your QMK environment [is setup][qmkintro].
- Make sure halves are not connected together with TRRS cable.
- Connect one half to USB, flash the firmware (always follow the actual instructions in the QMK documentation! The command might look something like this: `qmk flash -kb sofle/rev1 -km default`). Use the reset button to reset the keyboard when you are asked to in the console. 
- Connect the second half and flash it in the same way as the previous one.
- Disconnect the USB cable. Connect both halves together with your TRRS cable.
- Connect the USB cable to the **left** side[^1]. 
- Enjoy!

## Troubleshooting

## Modifications

## Links

- [Github with KiCad projects for the original Sofle][soflegithub]
- [Layout in KeyboardLayout editor][soflelayout]
- [QMK Firmware][qmk_firmware]
- [QMK Configurator][qmk_configurator]

## Footnotes

[^1]: This can be changed, look for [setting handednesss][qmkhandedness] in QMK documentation.

[layoutarticle]: <https://josef-adamcik.cz/electronics/in-search-of-the-best-custom-keyboard-layout.html> "In search of the best custom keyboard layout"
[introductionarticle]: <https://josef-adamcik.cz/electronics/let-me-introduce-you-sofle-keyboard-split-keyboard-based-on-lily58.html> "Let me introduce you SofleKeyboard - a split keyboard based on Lily58 and Crkbd"
[soflelayout]: http://www.keyboard-layout-editor.com/#/gists/76efb423a46cbbea75465cb468eef7ff "Sofle Keyboard layout at keyboard-layout-editor.com"
[soflegerber]: https://github.com/josefadamcik/SofleKeyboard/releases "SofleKeyboard - gerber files"
[qmk_firmware]: https://github.com/qmk/qmk_firmware/ "QMK firmware"
[qmk_configurator]: https://config.qmk.fm/#/sofle/rev1/LAYOUT "QMK configurator"
[springpinheader]: <https://yushakobo.jp/shop/a01mc-00/> "Spring pin headers - Japaneese"
[qmkprotonc]: https://qmk.fm/proton-c/ "QMK Proton-C"
[promicrosocketing]: <https://docs.splitkb.com/hc/en-us/articles/360011263059> "How do I socket a microcontroller? by splitkb.com"
[qmkintro]: <https://beta.docs.qmk.fm/tutorial/newbs_getting_started> "QMK getting started"
[qmkhandedness]: <https://docs.qmk.fm/#/feature_split_keyboard?id=setting-handedness> "QMK firmware - setting handedness"
[manufacturingproblems]: https://josef-adamcik.cz/electronics/corne-keyboard-build-log.html#manufacturing-at-jlcpcb---update-27112019 "Possible problems when manufacturing top plate for Corne"
[nooledlag]: https://github.com/qmk/qmk_firmware/issues/7522 "No OLED lag bug"
[soflegithub]: https://github.com/josefadamcik/SofleKeyboard "SofleKeyboard - KiCad project on Github.com"
[sourcing]: <{{ site.baseurl }}/sourcing_parts.html> "Sourcing parts"
[rgbbuildguide]: <{{ site.baseurl }}/build_guide_rgb.html> "Sofle RGB build guide"
[chocbuildguide]: <{{ site.baseurl }}/build_guide_choc.html> "Sofle Choc build guide"

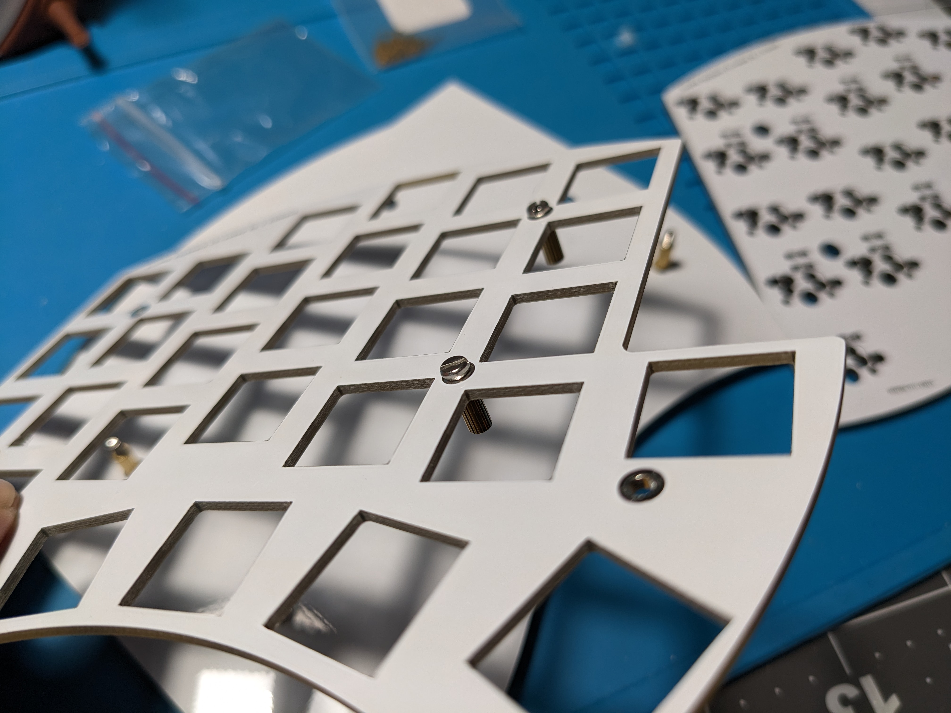
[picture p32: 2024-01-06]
docs/images/build_guide/PXL_20230415_152648130.jpg

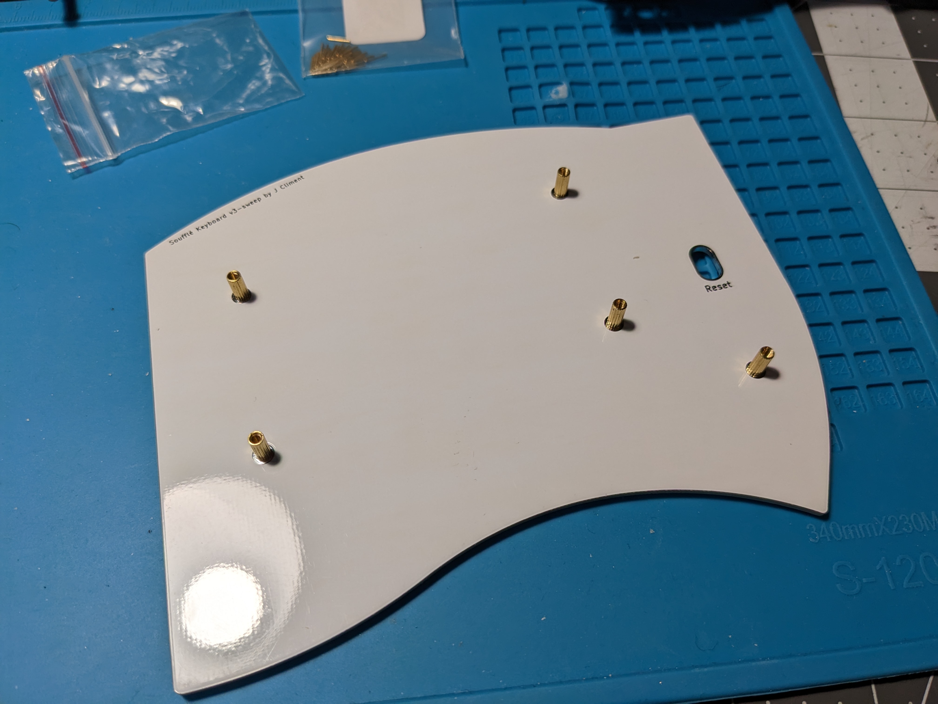
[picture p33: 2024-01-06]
docs/images/build_guide/PXL_20230415_152150104.jpg

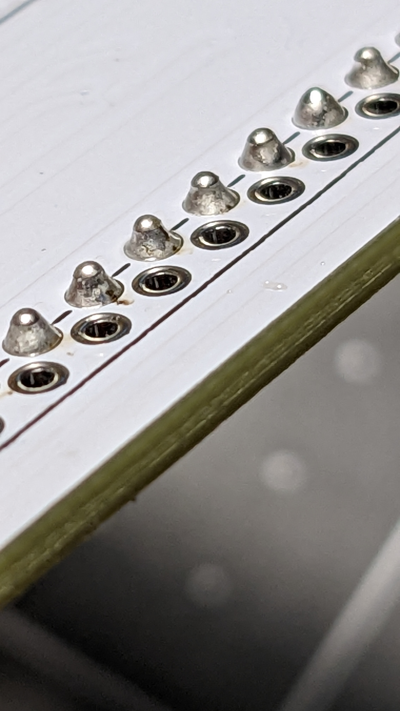
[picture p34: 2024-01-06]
docs/images/build_guide/PXL_20220824_180734124.jpg

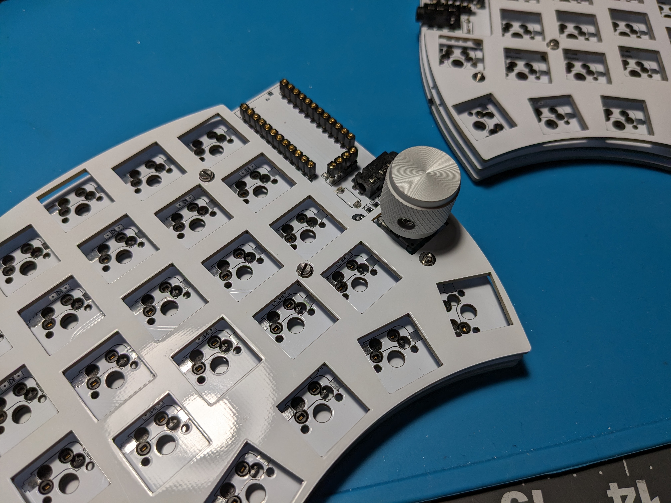
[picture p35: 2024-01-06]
docs/images/build_guide/PXL_20230415_153350561.jpg

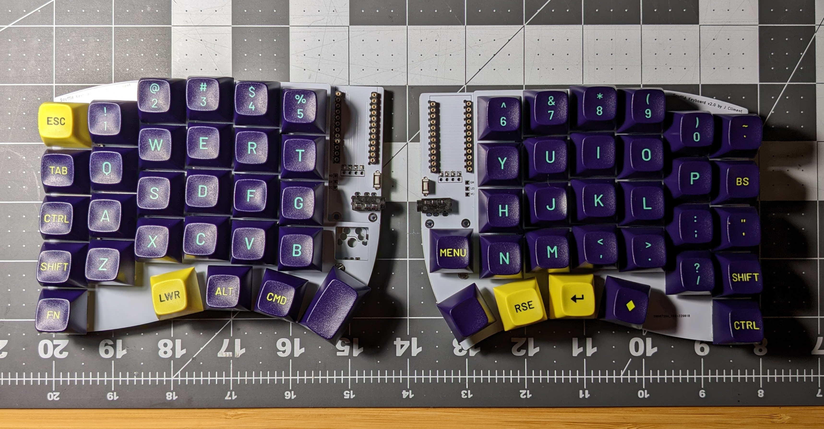
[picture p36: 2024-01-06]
docs/images/build_guide/PXL_20220824_211316296.jpg

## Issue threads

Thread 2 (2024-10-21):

Any critical issues with the previous V3 Sweep?

matru, 2024-10-21:
Hey, thanks for your work on the board. I have one laying around since last year, I believe it's the V3 of the MX version and I am wondering if it's safe (of issues) to build.

I see now there are some fixes "[Updated and fixed v3.2 as the order of the pads was incorrect.](https://github.com/climent/SouffleKeyboard/commit/4ca09d7c8aaca1b14398b6fbeec5d10cdc3c8563)". What pads are affected here, since previously to that a NiceView option was added?

climent, 2024-10-21:
What version of the keyboard you have? It should be in the corner of the board. If it either says "v3-sweep" or "v3.2.1-sweep" you should be fine. The problem with the v3.2 was specific to the OLED screen, where the pads were created in the wrong order, but everything should work fine.

matru, 2024-10-21:
on the pcbs it says v3-sweep indeed. But from what I see a version before the commit "Update tracks and moved boards to KiCad 7.x".

I already had it August/Sept 2023.

climent, 2024-10-22:
It should be fine. The update was mostly aesthetic, and should not affect functionality. I currently (typing this text) using a board that is similar to yours without any problem.

matru, 2024-10-23:
@climent thanks a lot, I really needed to make sure if everything would be fine, since I will also be selling the rest of my pcbs and saving one for me and a friend.

climent, 2024-10-23:
You can confirm it by checking how many holes you have for the OLED pins. if it is 4, you are 100% good.

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

matru, 2024-10-23:
Nice, I got them. Btw any issues not soldering the jumper pads for them if I don't use any OLED screens?

Closed 2024-11-04.

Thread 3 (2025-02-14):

3d printer files

tirorex, 2025-02-14:
Thank you for awesome keyboard!

Do you have files for 3d printer case for souffle v3?

climent, 2025-02-14:
I do not have 3d printer case files, but that's something it should not be hard to create. I may try to get them done at some point soon. I will keep this issue open to track when i manage to complete them.

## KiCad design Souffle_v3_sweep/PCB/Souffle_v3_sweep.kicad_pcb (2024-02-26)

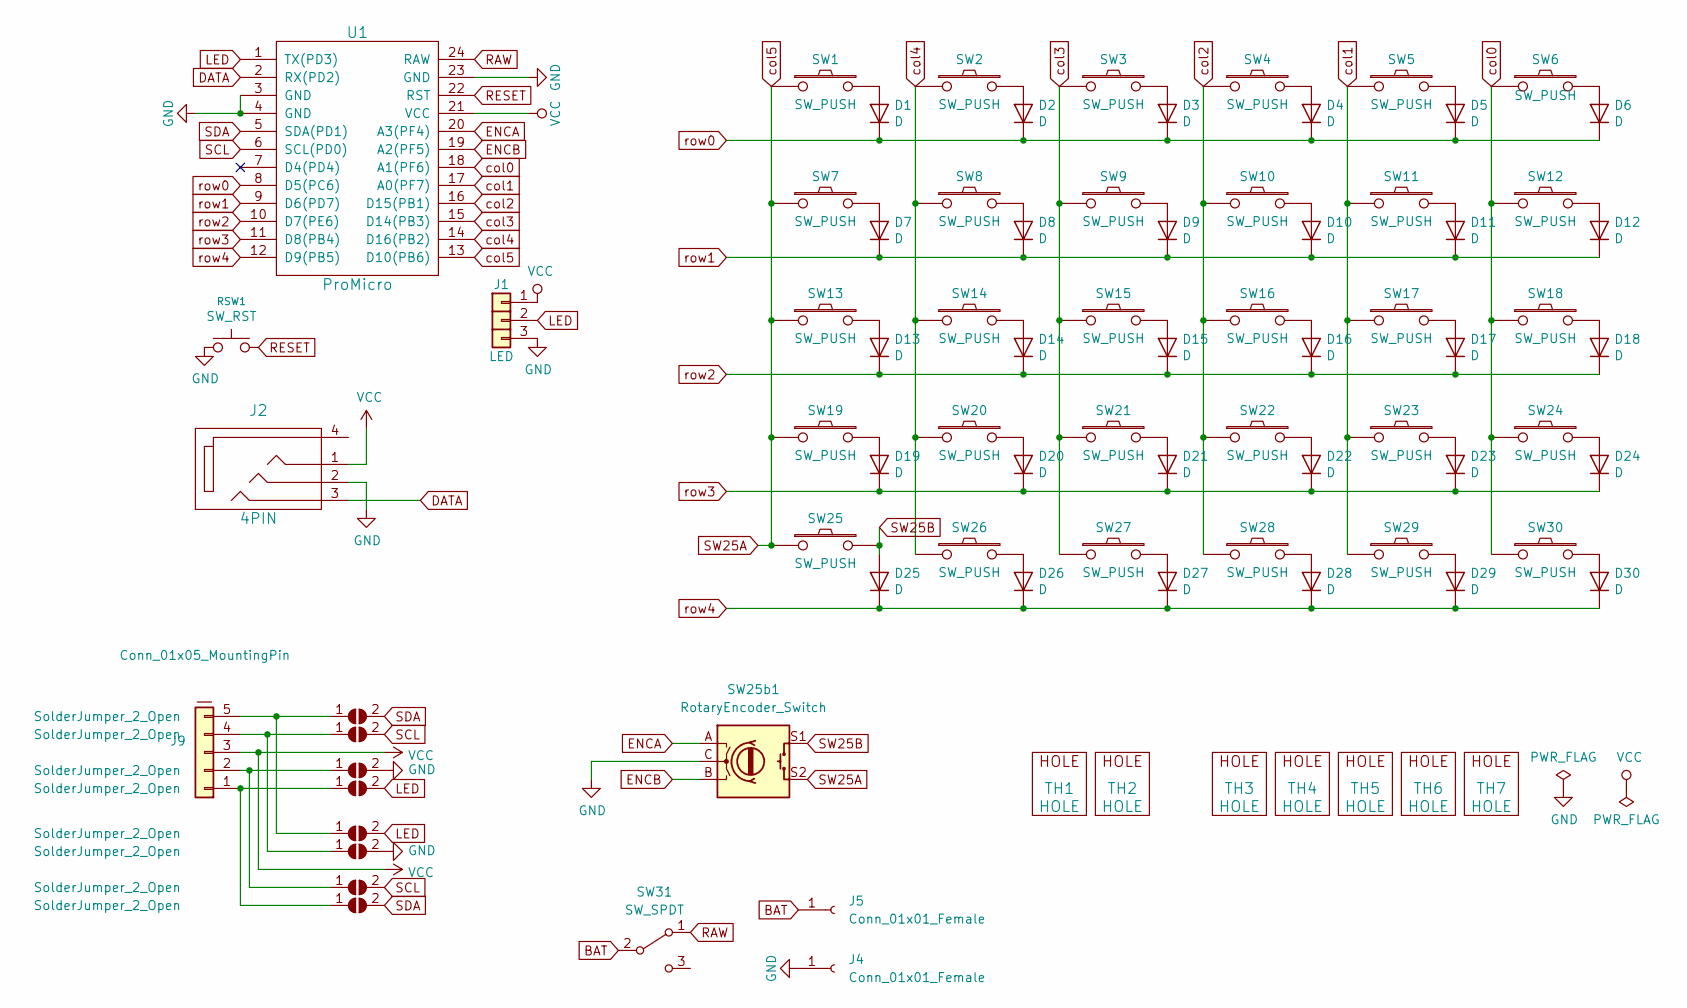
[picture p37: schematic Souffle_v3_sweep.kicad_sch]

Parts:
D1, D2, D3, D4, D5, D6, D7, D8, D9, D10, D11, D12, D13, D14, D15, D16, D17, D18, D19, D20, D21, D22, D23, D24, D25, D26, D27, D28, D29, D30: D; Diode_SOD123
J1: LED
J2: 4PIN; MJ-4PP-9
J4, J5: Conn_01x01_Female; PinSocket_1x01_P2.00mm_Vertical
J9: Conn_01x05_MountingPin; PinHeader_1x05_P2.54mm_Vertical
JP9, JP10, JP12, JP13, JP14, JP15, JP17, JP18: SolderJumper_2_Open; SolderJumper-2_P1.3mm_Open_Pad1.0x1.5mm
RSW1: SW_RST; TACT_SWITCH_TVBP06
SW1, SW2, SW3, SW4, SW5, SW6, SW7, SW8, SW9, SW10, SW11, SW12, SW13, SW14, SW15, SW16, SW17, SW18, SW19, SW20, SW21, SW22, SW23, SW24, SW27, SW28, SW29, SW30: SW_PUSH; CherryMX_KailhLowProfile_Hotswap
SW25, SW26: SW_PUSH; CherryMX_KailhLowProfile_Hotswap_1.5
SW25b1: RotaryEncoder_Switch; RotaryEncoder_Alps_EC11E-Switch_Vertical_H20mm
SW31: SW_SPDT; Switch_MSK-12C01-07
TH1, TH2: HOLE; M2_HOLE_PCB
TH3, TH4, TH5, TH6, TH7: HOLE; HOLE_M2_TH
U1: ProMicro

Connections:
BAT: J5.1, SW31.2 (B)
DATA: J2.3, U1.2 (RX(PD2))
ENCA: SW25b1.A, U1.20 (A3(PF4))
ENCB: SW25b1.B, U1.19 (A2(PF5))
GND: J1.3, J2.2, J4.1, JP12.2 (B), JP15.2 (B), RSW1.1, SW25b1.C, U1.3 (GND), U1.4 (GND), U1.23 (GND)
LED: J1.2, JP13.2 (B), JP14.2 (B), U1.1 (TX(PD3))
unnamed: D1.2 (A), SW1.2
unnamed: D2.2 (A), SW2.2
unnamed: D3.2 (A), SW3.2
unnamed: D4.2 (A), SW4.2
unnamed: D5.2 (A), SW5.2
unnamed: D6.2 (A), SW6.2
unnamed: D7.2 (A), SW7.2
unnamed: D8.2 (A), SW8.2
unnamed: D9.2 (A), SW9.2
unnamed: D10.2 (A), SW10.2
unnamed: D11.2 (A), SW11.2
unnamed: D12.2 (A), SW12.2
unnamed: D13.2 (A), SW13.2
unnamed: D14.2 (A), SW14.2
unnamed: D15.2 (A), SW15.2
unnamed: D16.2 (A), SW16.2
unnamed: D17.2 (A), SW17.2
unnamed: D18.2 (A), SW18.2
unnamed: D19.2 (A), SW19.2
unnamed: D20.2 (A), SW20.2
unnamed: D21.2 (A), SW21.2
unnamed: D22.2 (A), SW22.2
unnamed: D23.2 (A), SW23.2
unnamed: D24.2 (A), SW24.2
unnamed: D26.2 (A), SW26.2
unnamed: D27.2 (A), SW27.2
unnamed: D28.2 (A), SW28.2
unnamed: D29.2 (A), SW29.2
unnamed: D30.2 (A), SW30.2
unnamed: J9.1, JP13.1 (A), JP18.1 (A)
unnamed: J9.2, JP12.1 (A), JP17.1 (A)
unnamed: J9.4, JP10.1 (A), JP15.1 (A)
unnamed: J9.5, JP9.1 (A), JP14.1 (A)
RAW: SW31.1 (A), U1.24 (RAW)
RESET: RSW1.2, U1.22 (RST)
SCL: JP10.2 (B), JP17.2 (B), U1.6 (SCL(PD0))
SDA: JP9.2 (B), JP18.2 (B), U1.5 (SDA(PD1))
SW25A: SW1.1, SW7.1, SW13.1, SW19.1, SW25.1, SW25b1.S2, U1.13 (D10(PB6))
SW25B: D25.2 (A), SW25.2, SW25b1.S1
VCC: J1.1, J2.1, J9.3, U1.21 (VCC)
col0: SW6.1, SW12.1, SW18.1, SW24.1, SW30.1, U1.18 (A1(PF6))
col1: SW5.1, SW11.1, SW17.1, SW23.1, SW29.1, U1.17 (A0(PF7))
col2: SW4.1, SW10.1, SW16.1, SW22.1, SW28.1, U1.16 (D15(PB1))
col3: SW3.1, SW9.1, SW15.1, SW21.1, SW27.1, U1.15 (D14(PB3))
col4: SW2.1, SW8.1, SW14.1, SW20.1, SW26.1, U1.14 (D16(PB2))
row0: D1.1 (K), D2.1 (K), D3.1 (K), D4.1 (K), D5.1 (K), D6.1 (K), U1.8 (D5(PC6))
row1: D7.1 (K), D8.1 (K), D9.1 (K), D10.1 (K), D11.1 (K), D12.1 (K), U1.9 (D6(PD7))
row2: D13.1 (K), D14.1 (K), D15.1 (K), D16.1 (K), D17.1 (K), D18.1 (K), U1.10 (D7(PE6))
row3: D19.1 (K), D20.1 (K), D21.1 (K), D22.1 (K), D23.1 (K), D24.1 (K), U1.11 (D8(PB4))
row4: D25.1 (K), D26.1 (K), D27.1 (K), D28.1 (K), D29.1 (K), D30.1 (K), U1.12 (D9(PB5))

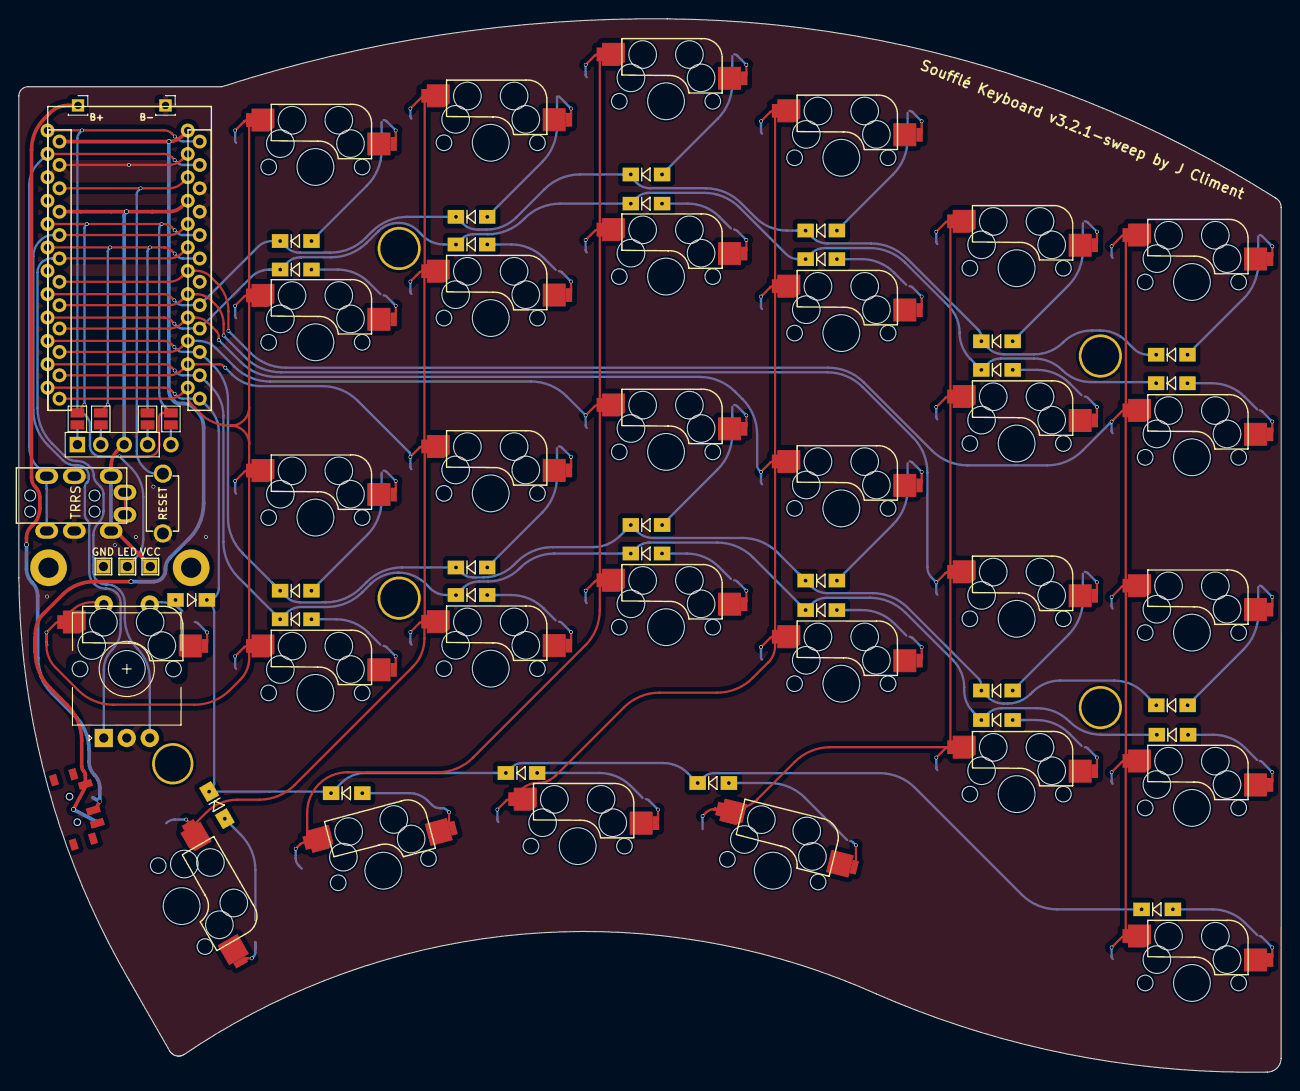
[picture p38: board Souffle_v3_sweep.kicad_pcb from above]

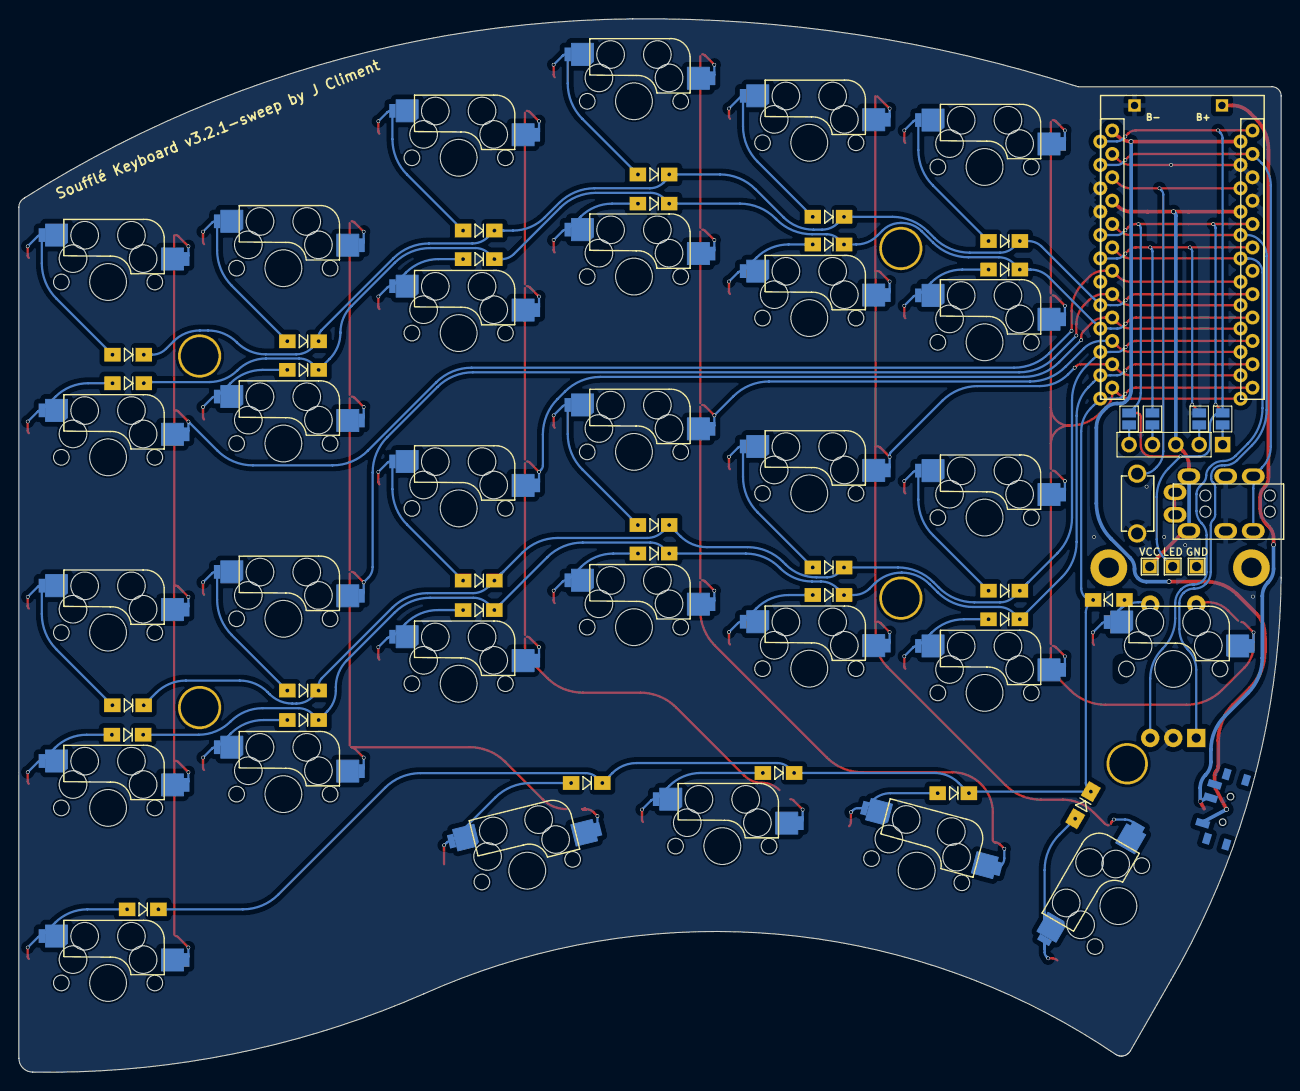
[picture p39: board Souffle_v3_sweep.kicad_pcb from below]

Board: 2 copper layers, 137.2 x 114.5 mm, 84 parts (4 on the bottom side), 56 nets.

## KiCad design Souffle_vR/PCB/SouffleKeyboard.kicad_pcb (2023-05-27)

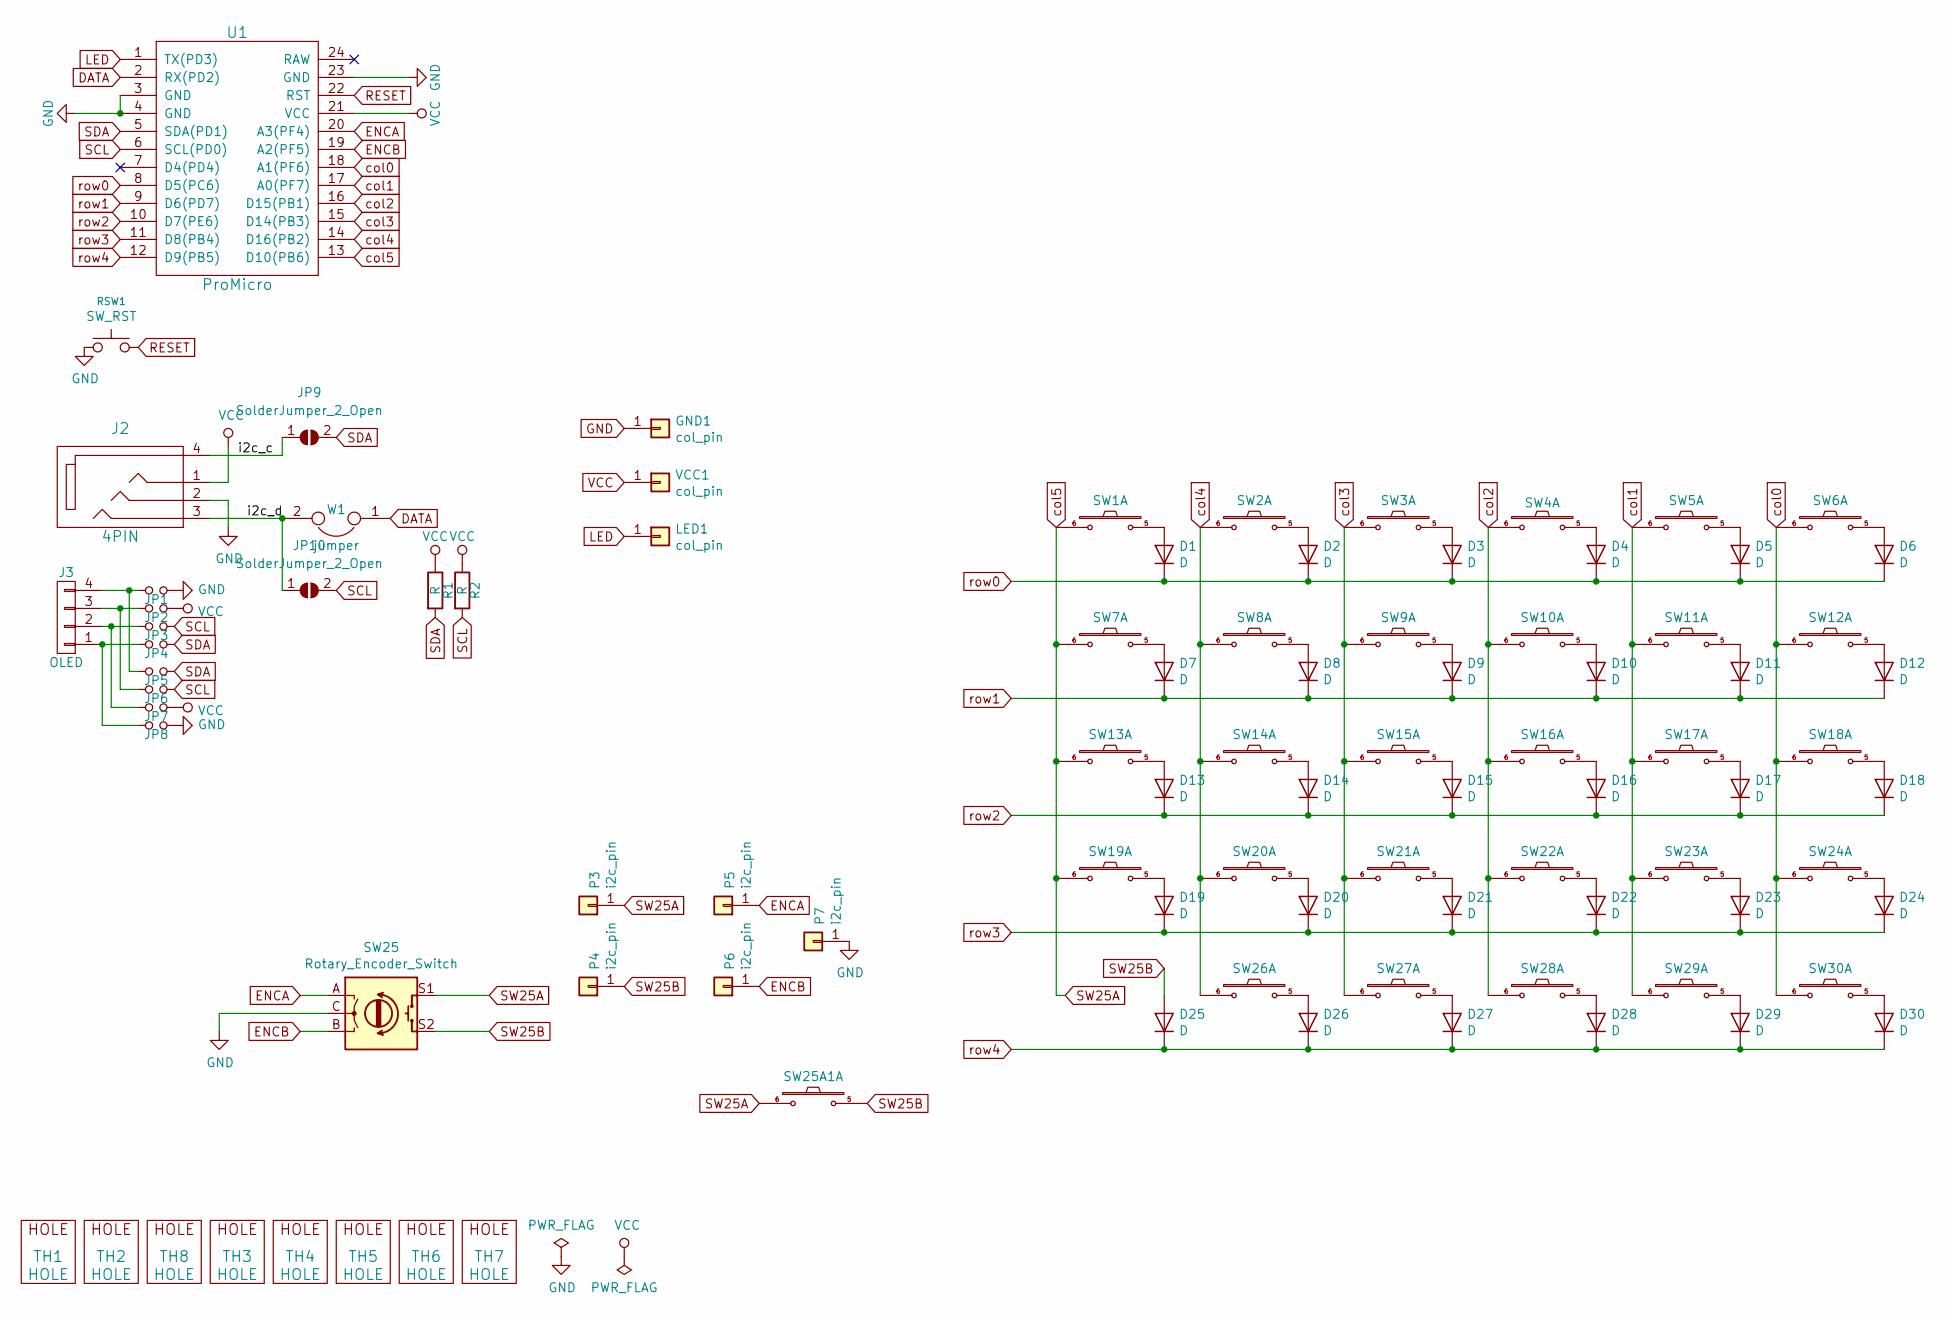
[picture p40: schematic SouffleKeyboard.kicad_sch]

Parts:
D1, D2, D3, D4, D5, D6, D7, D8, D9, D10, D11, D12, D13, D14, D15, D16, D17, D18, D19, D20, D21, D22, D23, D24, D25, D26, D27, D28, D29, D30: D; crkbd-diode
GND1: col_pin; 1pin_conn
J2: 4PIN; MJ-4PP-9
J3: OLED; OLED_4Pin
JP1, JP2, JP3, JP4, JP5, JP6, JP7, JP8: Jumper_NO_Small; Jumper
JP9, JP10: SolderJumper_2_Open; Jumper
LED1: col_pin; 1pin_conn
P3, P4, P5, P6, P7: i2c_pin; 1pin_conn
R1, R2: R; RESISTOR_mini
RSW1: SW_RST; TACT_SWITCH_TVBP06
SW1, SW2, SW3, SW4, SW5, SW6, SW7, SW8, SW9, SW10, SW11, SW12, SW13, SW14, SW15, SW16, SW17, SW18, SW19, SW20, SW21, SW22, SW23, SW24, SW25A1, SW26, SW27, SW28, SW29, SW30: SW_PUSH-MX_W_LED; SK6812MINI_and_cherry_NoLEDPads
SW25: Rotary_Encoder_Switch; RotaryEncoder_Alps_EC11E-Switch_Vertical_H20mm-keebio_modif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
TH1, TH2, TH8: HOLE; M2_HOLE_PCB
TH3, TH4, TH5, TH6, TH7: HOLE; HOLE_M2_TH
U1: ProMicro
VCC1: col_pin; 1pin_conn
W1: jumper; jumper_data

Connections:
/i2c_c: J2.4, JP9.1 (A)
/i2c_d: J2.3, JP10.1 (A), W1.2
DATA: U1.2 (RX(PD2)), W1.1
ENCA: P5.1, SW25.A, U1.20 (A3(PF4))
ENCB: P6.1, SW25.B, U1.19 (A2(PF5))
GND: GND1.1, J2.2, JP1.2, JP8.2, P7.1, RSW1.1, SW25.C, U1.3 (GND), U1.4 (GND), U1.23 (GND)
LED: LED1.1, U1.1 (TX(PD3))
unnamed: D1.2 (A), SW1.5
unnamed: D2.2 (A), SW2.5
unnamed: D3.2 (A), SW3.5
unnamed: D4.2 (A), SW4.5
unnamed: D5.2 (A), SW5.5
unnamed: D6.2 (A), SW6.5
unnamed: D7.2 (A), SW7.5
unnamed: D8.2 (A), SW8.5
unnamed: D9.2 (A), SW9.5
unnamed: D10.2 (A), SW10.5
unnamed: D11.2 (A), SW11.5
unnamed: D12.2 (A), SW12.5
unnamed: D13.2 (A), SW13.5
unnamed: D14.2 (A), SW14.5
unnamed: D15.2 (A), SW15.5
unnamed: D16.2 (A), SW16.5
unnamed: D17.2 (A), SW17.5
unnamed: D18.2 (A), SW18.5
unnamed: D19.2 (A), SW19.5
unnamed: D20.2 (A), SW20.5
unnamed: D21.2 (A), SW21.5
unnamed: D22.2 (A), SW22.5
unnamed: D23.2 (A), SW23.5
unnamed: D24.2 (A), SW24.5
unnamed: D26.2 (A), SW26.5
unnamed: D27.2 (A), SW27.5
unnamed: D28.2 (A), SW28.5
unnamed: D29.2 (A), SW29.5
unnamed: D30.2 (A), SW30.5
unnamed: J3.1, JP4.1, JP8.1
unnamed: J3.2, JP3.1, JP7.1
unnamed: J3.3, JP2.1, JP6.1
unnamed: J3.4, JP1.1, JP5.1
RESET: RSW1.2, U1.22 (RST)
SCL: JP3.2, JP6.2, JP10.2 (B), R2.2, U1.6 (SCL(PD0))
SDA: JP4.2, JP5.2, JP9.2 (B), R1.2, U1.5 (SDA(PD1))
SW25A: P3.1, SW1.6, SW7.6, SW13.6, SW19.6, SW25.S1, SW25A1.6, U1.13 (D10(PB6))
SW25B: D25.2 (A), P4.1, SW25.S2, SW25A1.5
VCC: J2.1, JP2.2, JP7.2, R1.1, R2.1, U1.21 (VCC), VCC1.1
col0: SW6.6, SW12.6, SW18.6, SW24.6, SW30.6, U1.18 (A1(PF6))
col1: SW5.6, SW11.6, SW17.6, SW23.6, SW29.6, U1.17 (A0(PF7))
col2: SW4.6, SW10.6, SW16.6, SW22.6, SW28.6, U1.16 (D15(PB1))
col3: SW3.6, SW9.6, SW15.6, SW21.6, SW27.6, U1.15 (D14(PB3))
col4: SW2.6, SW8.6, SW14.6, SW20.6, SW26.6, U1.14 (D16(PB2))
row0: D1.1 (K), D2.1 (K), D3.1 (K), D4.1 (K), D5.1 (K), D6.1 (K), U1.8 (D5(PC6))
row1: D7.1 (K), D8.1 (K), D9.1 (K), D10.1 (K), D11.1 (K), D12.1 (K), U1.9 (D6(PD7))
row2: D13.1 (K), D14.1 (K), D15.1 (K), D16.1 (K), D17.1 (K), D18.1 (K), U1.10 (D7(PE6))
row3: D19.1 (K), D20.1 (K), D21.1 (K), D22.1 (K), D23.1 (K), D24.1 (K), U1.11 (D8(PB4))
row4: D25.1 (K), D26.1 (K), D27.1 (K), D28.1 (K), D29.1 (K), D30.1 (K), U1.12 (D9(PB5))

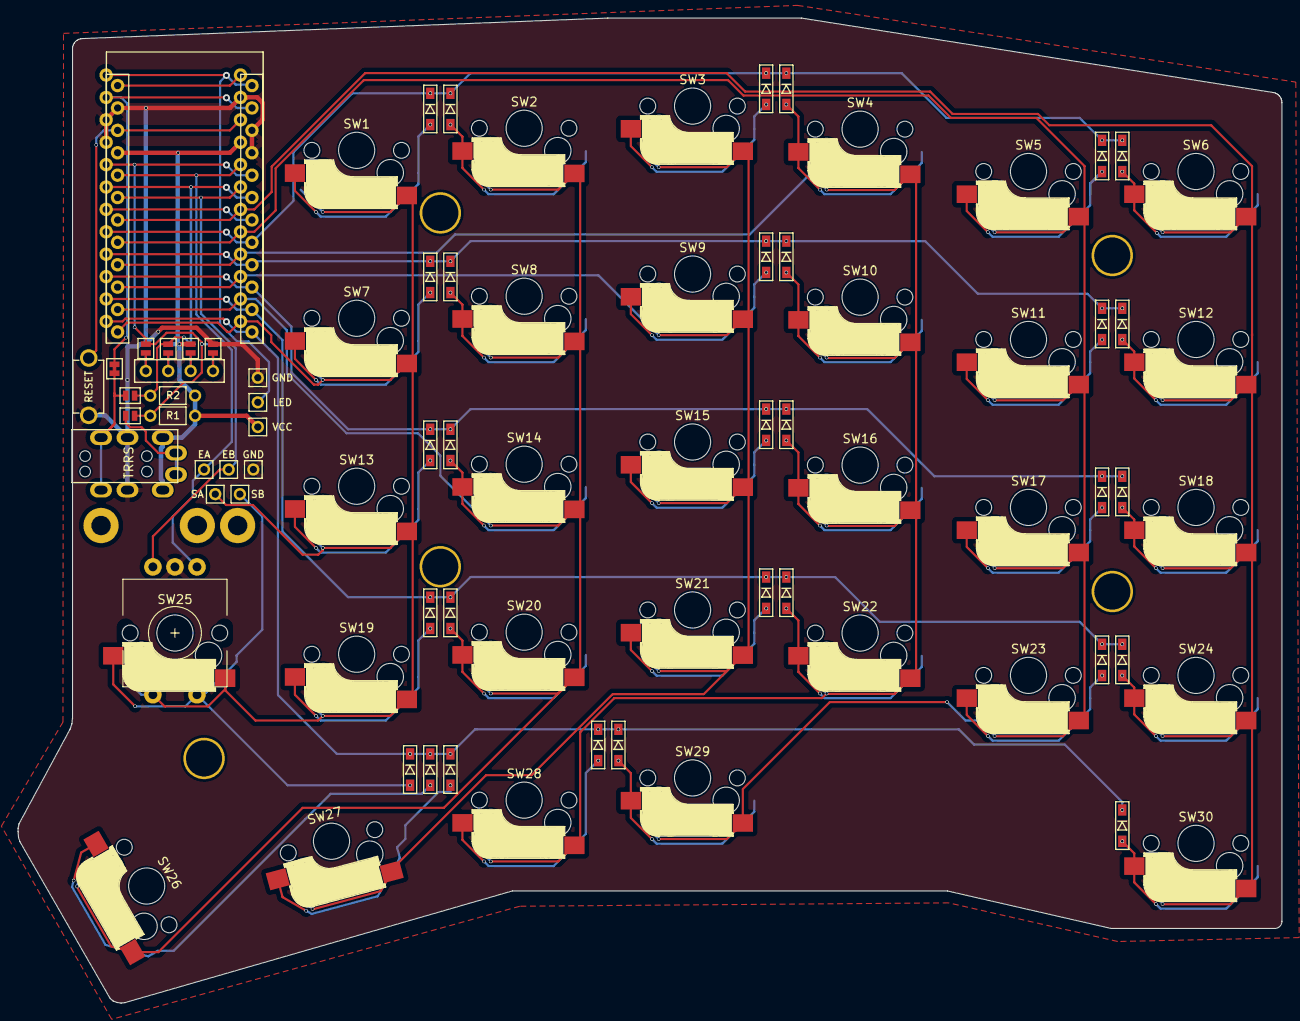
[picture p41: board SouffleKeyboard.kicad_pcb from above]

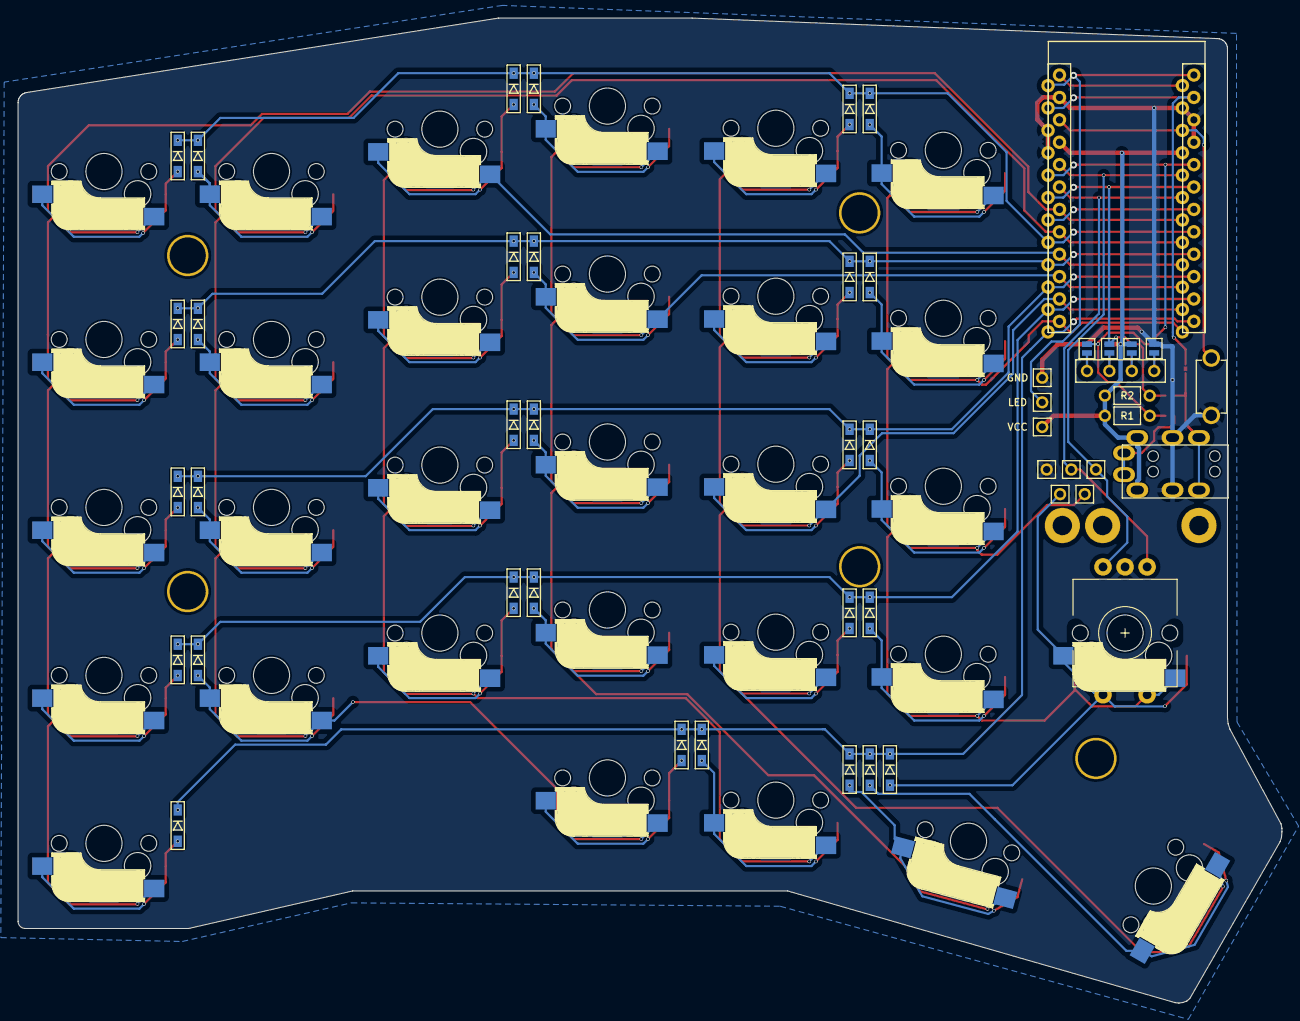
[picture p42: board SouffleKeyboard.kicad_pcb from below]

Board: 2 copper layers, 143.3 x 111.7 mm, 94 parts (4 on the bottom side), 56 nets.

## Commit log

2022-07-24 Initial release of the Soufflé v2.
    [Souffle_v2.kicad_pcb, Souffle_v2.kicad_sch, Souffle_v2_Case_Bottom.kicad_pcb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]
2022-07-24 Added gerbers, updated README.
    [Souffle_v2.kicad_pcb, Souffle_v2_Case_Bottom.kicad_pcb, Souffle_v2_Case_Top.kicad_pcb]
2022-07-31 Rotated reset key for shorter track.
    [Souffle_v2.kicad_pcb]
2022-07-31 Fix track for column 2. Was unconnected.
    [Souffle_v2.kicad_pcb]
2022-07-31 Exported gerber files for fixed v2.
    [Souffle_v2.kicad_pcb]
2022-07-31 Souffle v1.
    [SouffleKeyboard.kicad_pcb, SouffleKeyboard.sch, SouffleKeyboard_case_upper.kicad_pcb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]
2022-07-31 Souffle vR (modeled after the Sofle RGB)..
    [SofleKeyboardBottomPlate.kicad_pcb, SofleKeyboardTopPlate.kicad_pcb, SouffleKeyboard.kicad_pcb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]
2022-08-01 Added case plate with roller encoder.
    [SofleKeyboardTopPlate_Encoder.kicad_pcb]
2022-08-01 Added case with partial drilling of holes.
    [SouffleKeyboard_case_upper_partial.kicad_pcb]
2022-08-01 Small tweaks.
    [SofleKeyboardBottomPlate.kicad_pcb, SofleKeyboardTopPlate.kicad_pcb]
2022-08-25 Small fix for 2u keys in the thumb cluster touching the OLED key.
    [Souffle_v2.kicad_pcb, Souffle_v2_Case_Top.kicad_pcb]
2023-04-01 Soufflé v3 Sweep keyboard.
    [Souffle_v3_sweep.kicad_pcb, Souffle_v3_sweep.kicad_sch, Souffle_v3_sweep_bottom.kicad_pcb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]
2023-04-01 Gerber files doe v3.
2023-04-02 Updated README with BOM.
2023-04-03 Updated BOM.
2023-04-18 Fixed error in GND not connected on the right side of the OLED pads, and other small cleanups.
    [Souffle_v3_sweep.kicad_pcb]
2023-04-19 Release Choc version by merging Souffle_v3_sweep_choc branch to main repo with all the fixes.
    [Souffle_v3_sweep_choc.kicad_pcb, Souffle_v3_sweep_choc.kicad_sch, Souffle_v3_sweep_choc_bottom.kicad_pcb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]
2023-04-19 Push reset button away from the TRRS conenctor.
    [Souffle_v3_sweep_choc.kicad_pcb]
2023-04-20 Small changes to make sure the components do not touch each other or the board.
    [Souffle_v3_sweep_choc.kicad_pcb, Souffle_v3_sweep_choc_bottom.kicad_pcb]
2023-04-20 Gerber files for the Choc v3 board.
2023-04-23 Gerber file for the corrected PCB.
2023-04-23 Corrected PCB with displaced encoder.
    [Souffle_v3_sweep.kicad_pcb]
2023-04-26 Added steps for soldering pins and micro.
2023-05-27 Small updates on the VR release.
    [SofleKeyboardBottomPlate-B_Cu.gbl, SofleKeyboardBottomPlate-B_Mask.gbs, SofleKeyboardBottomPlate-B_Silkscreen.gbo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]
2023-05-27 Added gerbers for vR.
2023-05-27 Removed gerber leftover files.
    [SofleKeyboardBottomPlate-B_Cu.gbl, SofleKeyboardBottomPlate-B_Mask.gbs, SofleKeyboardBottomPlate-B_Silkscreen.gbo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]
2023-05-27 Updated to KiCad 7
    [SouffleKeyboard.kicad_pcb]
2023-11-09 Update tracks and moved boards to KiCad 7.x
    [SouffleKeyboard.kicad_pcb, Souffle_v2.kicad_pcb, Souffle_v3_sweep.kicad_pcb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]
2023-11-11 Updated PCB image in README.
2024-01-04 Updated OLED connection to accomodate for NiceView option.
    [Souffle_v3_sweep.kicad_pcb, Souffle_v3_sweep.kicad_sch]
2024-01-06 Added Gerber file for 3.1.
2024-02-24 V3.2 of the Soufflé keyboard, with reworked NiceView pins
    [Souffle_v3_sweep.kicad_pcb, Souffle_v3_sweep.kicad_sch]
2024-02-26 Updated and fixed v3.2 as the order of the pads was incorrect. Release v3.2.1 with the fix.
    [Souffle_v3_sweep.kicad_pcb, Souffle_v3_sweep.kicad_sch]
